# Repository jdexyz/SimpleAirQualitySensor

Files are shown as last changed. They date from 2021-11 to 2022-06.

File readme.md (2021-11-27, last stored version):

# (A) Simple Air Quality Sensor

### Parts

All parts were bought from https://shop.pimoroni.com/

- [Adafruit MagTag - 2.9" Grayscale E-Ink WiFi Display](https://www.adafruit.com/product/4800)
- [Adafruit CCS811 Air Quality Sensor Breakout](https://www.adafruit.com/product/3566)
- [Adafruit PMSA003I Air Quality Breakout](https://www.adafruit.com/product/4632)
- [Adafruit SCD-41 - True CO2 Temperature and Humidity Sensor](https://www.adafruit.com/product/5190)
- [MICS6814 3-in-1 Gas Sensor Breakout (CO, NO2, NH3)](https://shop.pimoroni.com/products/mics6814-gas-sensor-breakout)
- [BME688 4-in-1 Air Quality Breakout](https://shop.pimoroni.com/products/bme688-breakout)
- [LiPo Battery Pack – 2000mAh](https://shop.pimoroni.com/products/lipo-battery-pack?variant=20429082247)

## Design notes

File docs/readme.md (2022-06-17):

# (A) Simple Air Quality Sensor

### Parts

All parts were bought from https://shop.pimoroni.com/

- [Adafruit MagTag - 2.9" Grayscale E-Ink WiFi Display](https://www.adafruit.com/product/4800)
- [Adafruit CCS811 Air Quality Sensor Breakout](https://www.adafruit.com/product/3566)
- [Adafruit PMSA003I Air Quality Breakout](https://www.adafruit.com/product/4632)
- [Adafruit SCD-41 - True CO2 Temperature and Humidity Sensor](https://www.adafruit.com/product/5190)
- [MICS6814 3-in-1 Gas Sensor Breakout (CO, NO2, NH3)](https://shop.pimoroni.com/products/mics6814-gas-sensor-breakout)
- [BME688 4-in-1 Air Quality Breakout](https://shop.pimoroni.com/products/bme688-breakout)
- [LiPo Battery Pack – 2000mAh](https://shop.pimoroni.com/products/lipo-battery-pack?variant=20429082247)

## A clueless but quick method for creating 3D boards from Eagle

At some point, with the integration of Eagle in Fusion 360, I thought I could open Eagle board files from Adafruit/Sparkfun and get in one click a 3D model in Fusion 360.

This did not happen. I spent a few hours trying to get the libraries right, but I am still confused and definitely not successful. However, I can quickly get the board with rough components placed, which is enough for me.

I ended up doing the following :

1. Open the board in Eagle. I used the latest version of Eagle as of March 2022, Eagle 9.6.

2. Click on the Manufacturing tab on the right. Click on the settings icon, and choose "SolderMask Color". Choose the appropriate color.

3. Click on the Fusion 360 tab to create a new board there.

4. In Fusion, open the generated model. 

5. Find the board packages, then right click and "Save a Copy".

6. Open the new Packages model, it is now a normal 3D model, instead of a 3D PCB.

7. In the data panel, click on the previous 3D PCB model and insert it in the current model.

8. Break the link of the inserted model and delete its packages.

9. Next clean up the model, removing the rectangle placeholders in front of holes, vias, etc.

10. Then import all 3D models of important parts manually. I only did this for big components that matter in mechanical assembly.

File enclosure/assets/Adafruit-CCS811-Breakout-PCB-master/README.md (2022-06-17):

## Adafruit CCS811 Breakout PCB

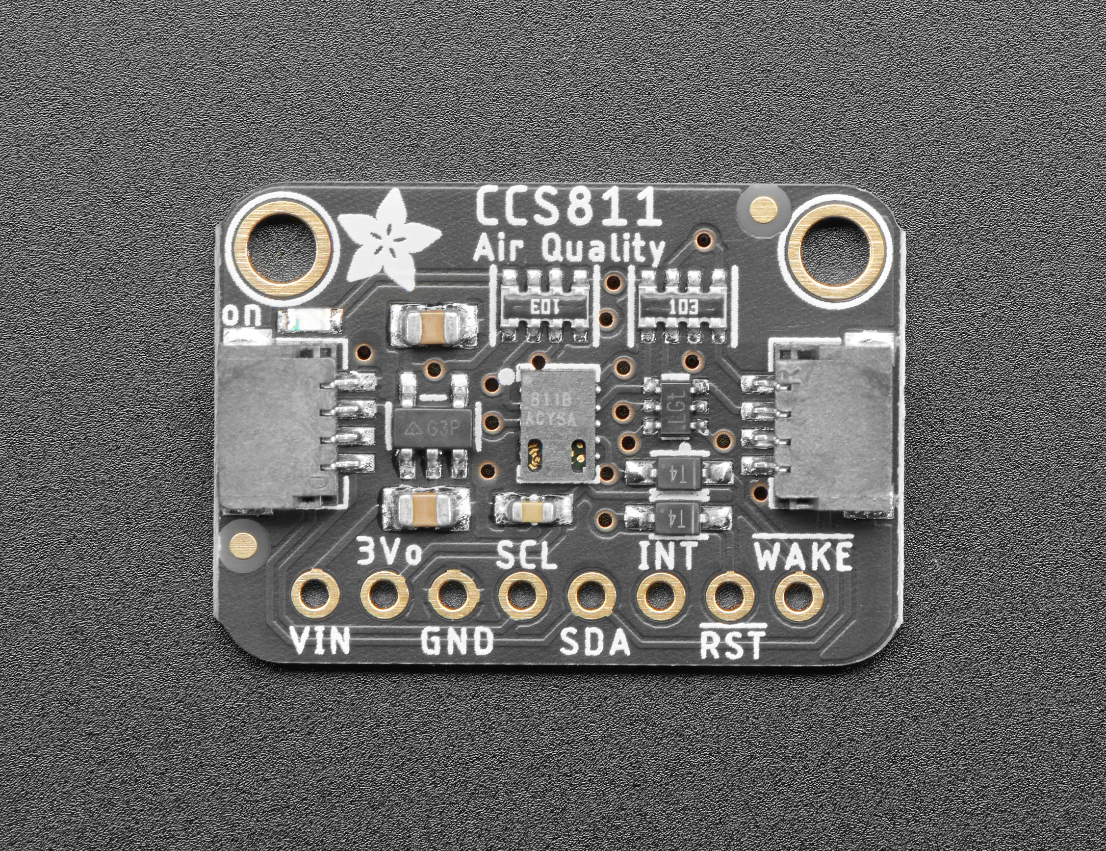
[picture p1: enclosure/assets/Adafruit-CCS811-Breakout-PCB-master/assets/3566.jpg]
<a href="http://www.adafruit.com/products/3566"><br/>
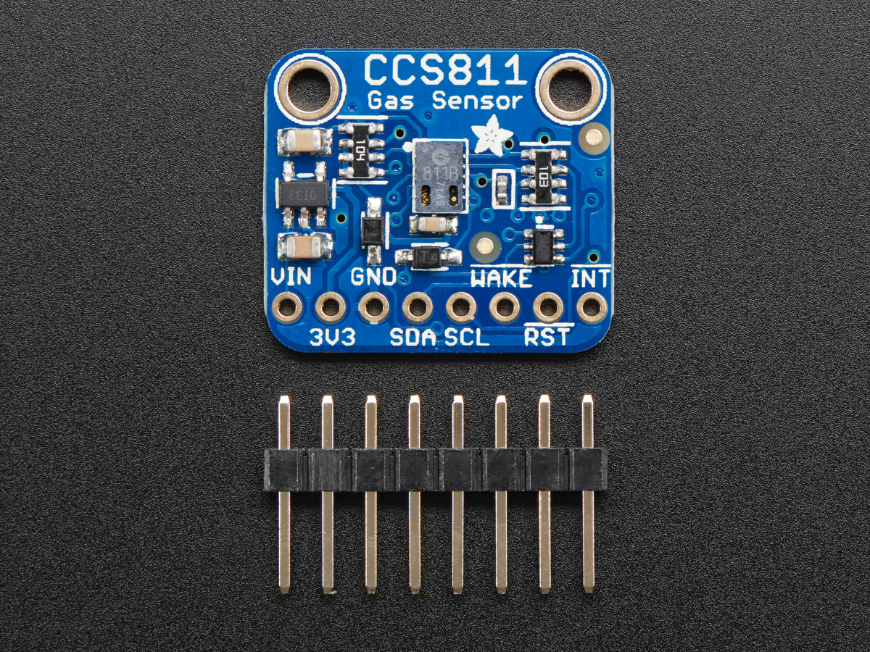
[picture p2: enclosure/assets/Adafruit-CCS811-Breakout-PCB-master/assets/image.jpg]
<a href="http://www.adafruit.com/products/3566"><br/>
Click here to purchase one from the Adafruit shop</a>

PCB files for the Adafruit CCS811 air quality sensor breakout board. Format is EagleCAD schematic and board layout

For more details, check out the product page at
* https://www.adafruit.com/products/3566

### Description

Breathe easy - we finally have an I2C VOC/eCO2 sensor in the Adafruit shop! Add air quality monitoring to your project and with an Adafruit CCS811 Air Quality Sensor Breakout. This sensor from AMS is a gas sensor that can detect a wide range of Volatile Organic Compounds (VOCs) and is intended for indoor air quality monitoring. When connected to your microcontroller (running our library code) it will return a Total Volatile Organic Compound (TVOC) reading and an equivalent carbon dioxide reading (eCO2) over I2C. There is also an onboard thermistor that can be used to calculate the local ambient temperature.

The CCS811 has a 'standard' hot-plate MOX sensor, as well as a small microcontroller that controls power to the plate, reads the analog voltage, and provides an I2C interface to read from.

This part will measure eCO2 (equivalent calculated carbon-dioxide) concentration within a range of 400 to 8192 parts per million (ppm), and TVOC (Total Volatile Organic Compound) concentration within a range of 0 to 1187 parts per billion (ppb). According to the fact sheet it can detect Alcohols, Aldehydes, Ketones, Organic Acids, Amines, Aliphatic and Aromatic Hydrocarbons. We include a 10K NTC thermistor with matching balancing resistor which can be read by the CCS811 to calculate approximate temperature.

Please note, this sensor, like all VOC/gas sensors, has variability and to get precise measurements you will want to calibrate it against known sources! That said, for general environmental sensors, it will give you a good idea of trends and comparisons.Also, AMS recommends that you run this sensor for 48 hours when you first receive it to "burn it in", and then 20 minutes in the desired mode every time the sensor is in use. This is because the sensitivity levels of the sensor will change during early use. Finally, this chip uses I2C clock stretching, and some microcontrollers/computers don't support that. It is now possible to [use with Raspberry Pi](https://learn.adafruit.com/circuitpython-on-raspberrypi-linux/i2c-clock-stretching).

The CCS811 has a configurable interrupt pin that can fire when a conversion is ready and/or when a reading crosses a user-settable threshold. The CCS811 supports multiple drive modes to take a measurement every 1 second, every 10 seconds, every 60 seconds, or every 250 milliseconds.

Nice sensor right? So we made it easy for you to get right into your next project. The surface-mount sensor is soldered onto a custom made PCB in the STEMMA QT form factor, making them easy to interface with. The STEMMA QT connectors on either side are compatible with the SparkFun Qwiic I2C connectors. This allows you to make solderless connections between your development board and the SGP30 or to chain it with a wide range of other sensors and accessories using a compatible cable.

For your convenience we've pick-and-placed the sensor on a PCB with a 3.3V regulator and some level shifting so it can be easily used with your favorite 3.3V or 5V microcontroller.
### License

Adafruit invests time and resources providing this open source design, please support Adafruit and open-source hardware by purchasing products from [Adafruit](https://www.adafruit.com)!

Designed by Limor Fried/Ladyada for Adafruit Industries.

Creative Commons Attribution/Share-Alike, all text above must be included in any redistribution. See license.txt for additional details.

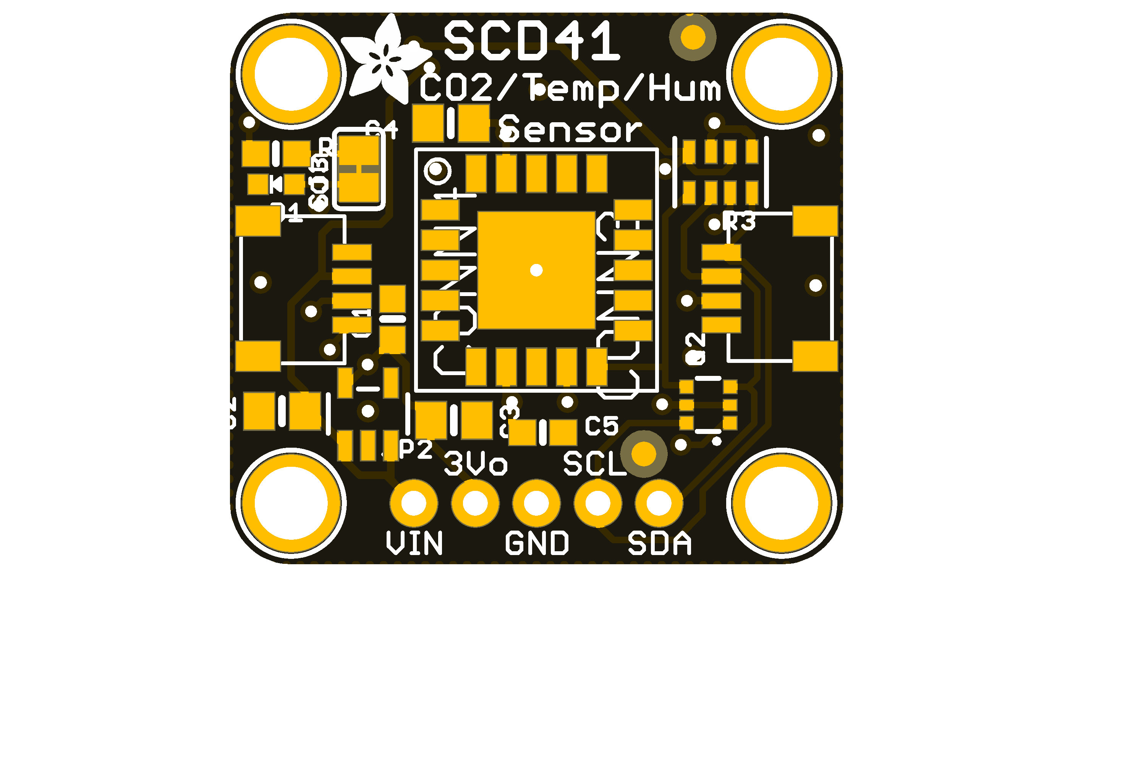
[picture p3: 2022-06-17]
enclosure/assets/Adafruit-SCD-4x-PCB-main/Adafruit SCD-41_top.png

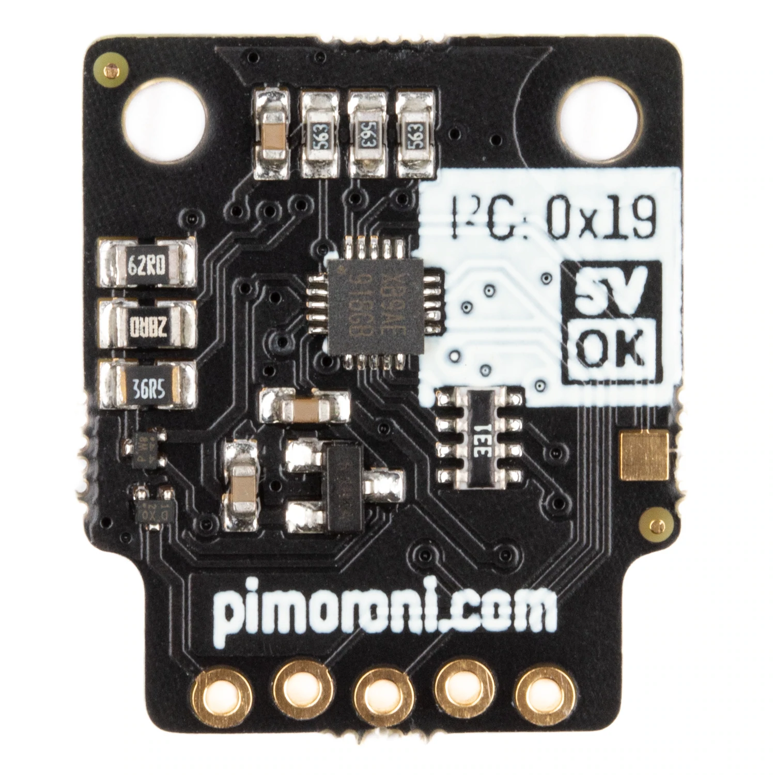
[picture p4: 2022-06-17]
enclosure/assets/MICS6814/MICS6814breakout_3of3_1500x1500.png

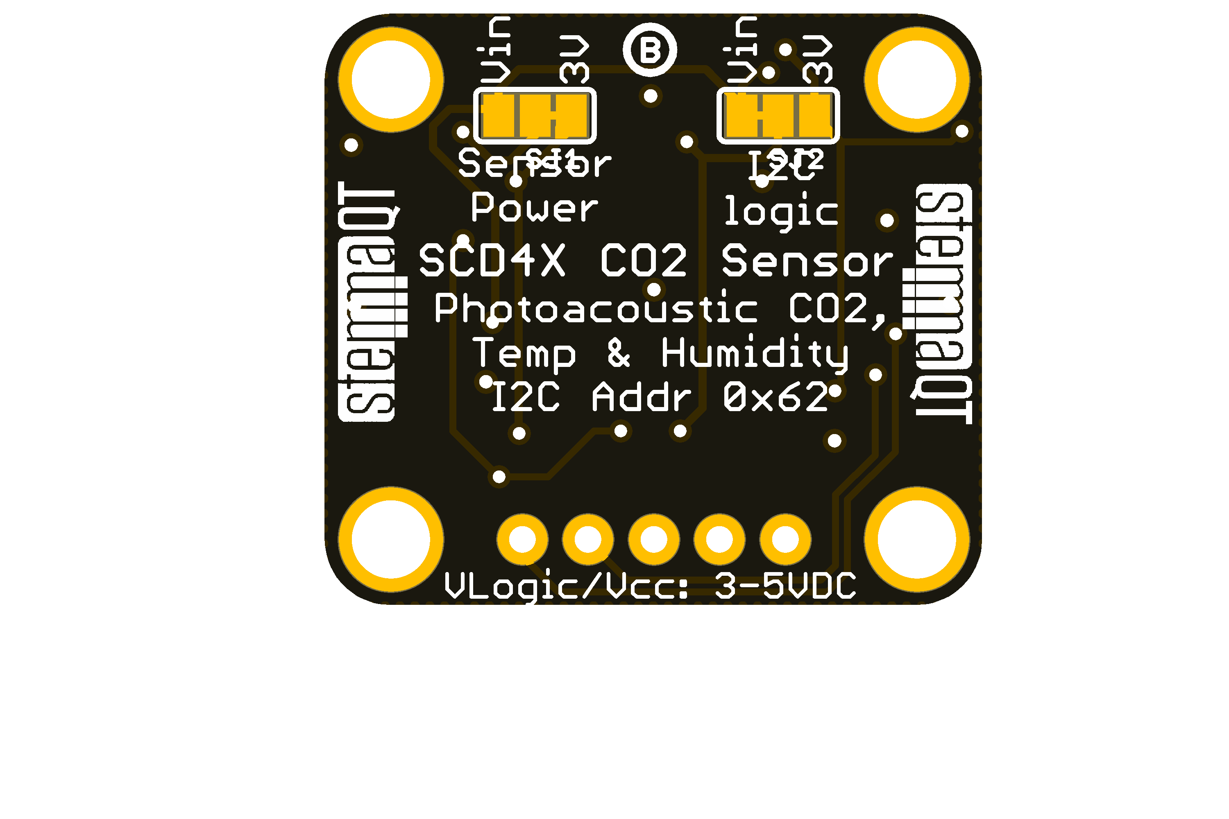
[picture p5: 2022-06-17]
enclosure/assets/Adafruit-SCD-4x-PCB-main/Adafruit SCD-41_bottom.png

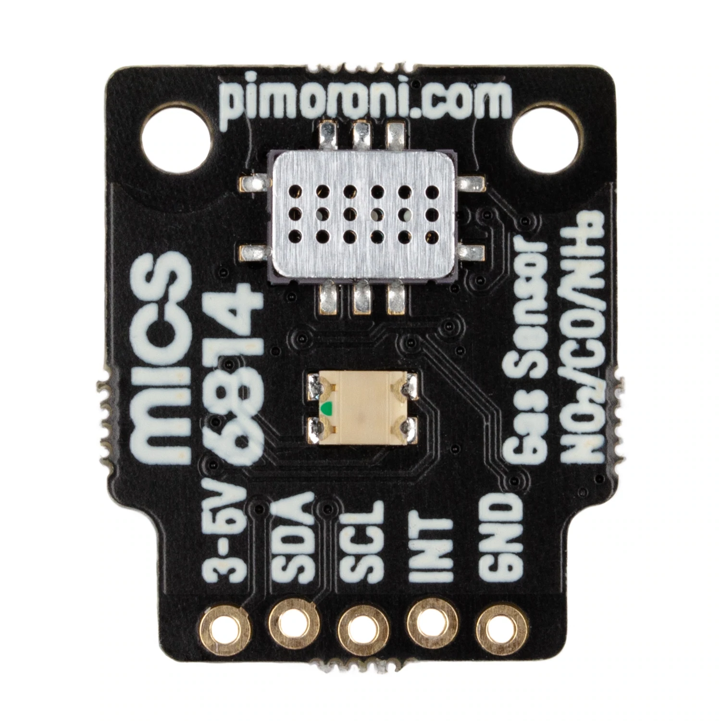
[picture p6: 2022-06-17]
enclosure/assets/MICS6814/MICS6814breakout_2of3_1500x1500.png

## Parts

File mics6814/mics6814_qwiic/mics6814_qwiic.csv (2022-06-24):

Id | Designator | Package | Quantity | Designation | Supplier and ref |  | H
1 | R8,R7 | 805 | 2 | 10k |  | k
2 | JP8 | SMT-JUMPER_2_NC_TRACE_SILK | 1 | PULL UP SCL
3 | JP7 | SMT-JUMPER_2_NC_TRACE_SILK | 1 | PULL UP SDA
4 | JP4 | SMT-JUMPER_2_NC_TRACE_SILK | 1 | HEAT LED
5 | JP2 | SMT-JUMPER_2_NC_TRACE_SILK | 1 | Power LED
6 | JP5 | SMT-JUMPER_2_NC_TRACE_SILK | 1 | alert
7 | U2 | SOT353 | 1 | 74HC1G04 |  | k
8 | Q1 | SOT23-3 | 1 | MOSFET_PCH-DMG2307L |  | K
9 | 1uH | 805 | 1 | INDUCTOR-0805-3.3UH |  | K
10 | 1uF | 805 | 1 | 1.0UF-0805-25V-10% |  | K
11 | MICS6814 | MICS6814 | 1 | MiCS-6814 |  | K
12 | D2 | LED-0603 | 1 | LED-RED1206 |  | K
13 | R6,R1 | 805 | 2 | 56k |  | K
14 | R5 | 805 | 1 | 1K |  | K
15 | R4 | 805 | 1 | 75R |  | K
16 | R3 | 805 | 1 | 10R |  | K
17 | R2 | 805 | 1 | 510R |  | K
18 | D1 | LED-0603 | 1 | Power |  | K
19 | JP6 | SMT-JUMPER_3_1-NC_TRACE_SILK | 1 | VSW
20 | JP3 | SMT-JUMPER_3_NO_SILK | 1 | ADDR2
21 | JP1 | SMT-JUMPER_3_1-NC_TRACE_SILK | 1 | ADDR1
22 | J2,J1 | 1X04_1MM_RA | 2 | QWIIC_CONNECTORJS-1MM |  | K
23 | U1 | TSSOP-10_3x3mm_P0.5mm | 1 | ADS1115 |  | K

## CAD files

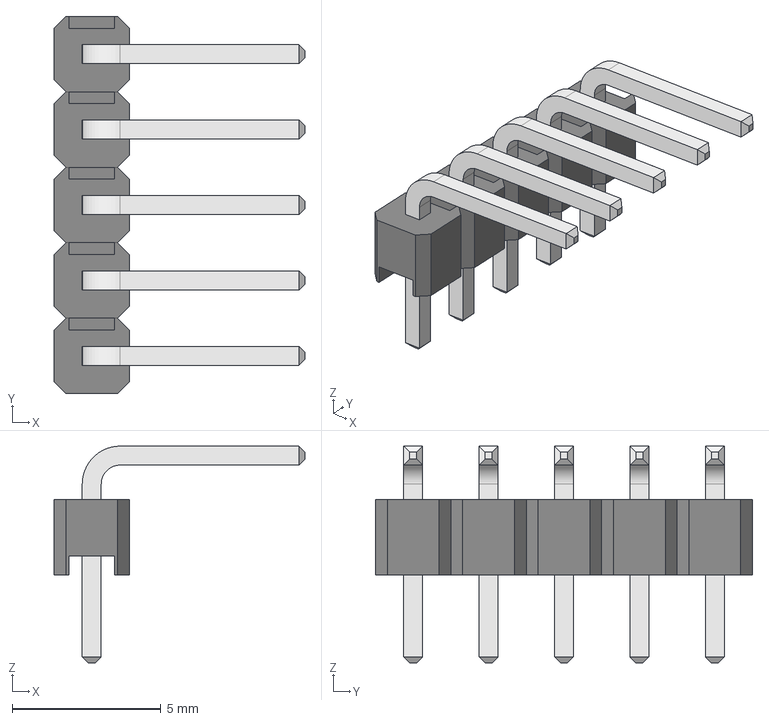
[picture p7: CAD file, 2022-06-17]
enclosure/assets/MICS6814/5Pin.step
8.45 x 12.7 x 7.30 mm

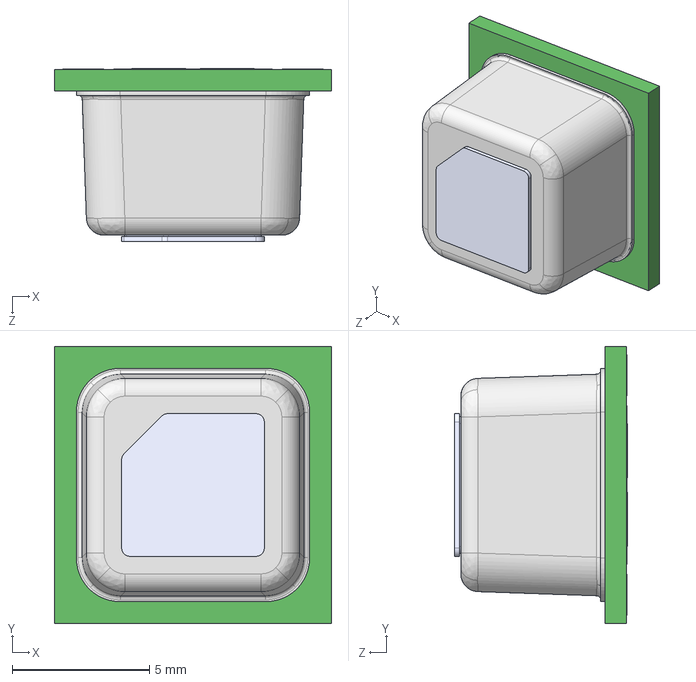
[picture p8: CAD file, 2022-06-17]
enclosure/assets/SCD41-D-R2--3DModel-STEP-369182.STEP
10.1 x 10.1 x 6.31 mm

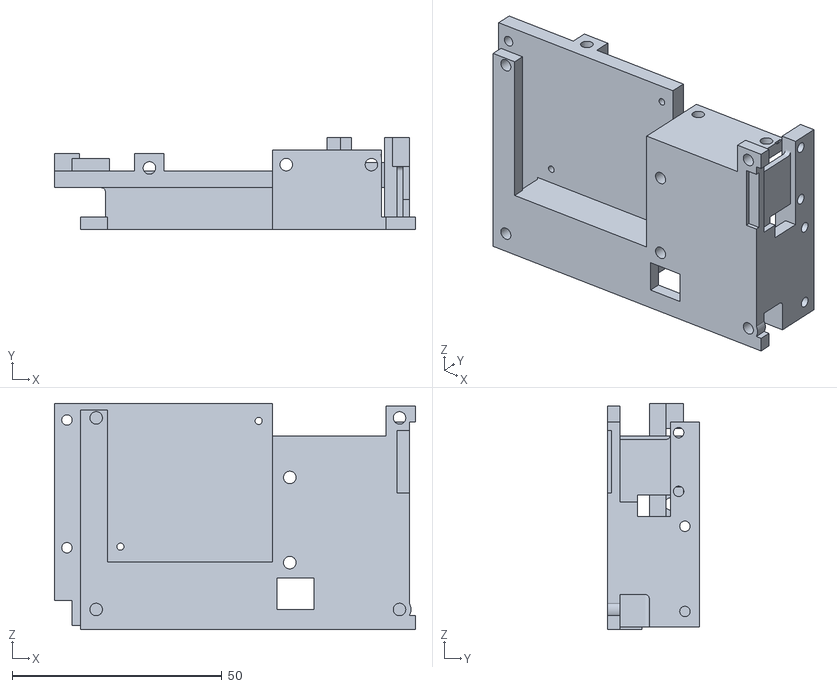
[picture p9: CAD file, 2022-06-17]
enclosure/exports/Inner.stl
86.1 x 22.0 x 54.0

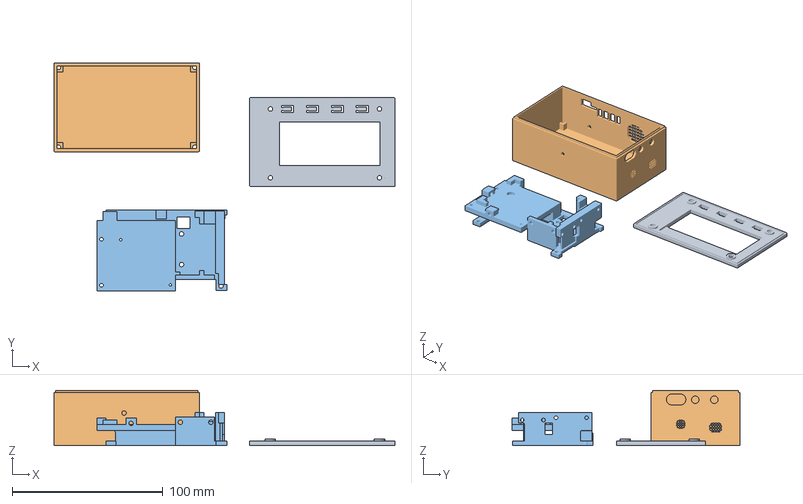
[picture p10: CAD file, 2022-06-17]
enclosure/Print.3mf
226.4 x 151.6 x 36.7 mm
Top.stl
Outer.stl
Inner.stl

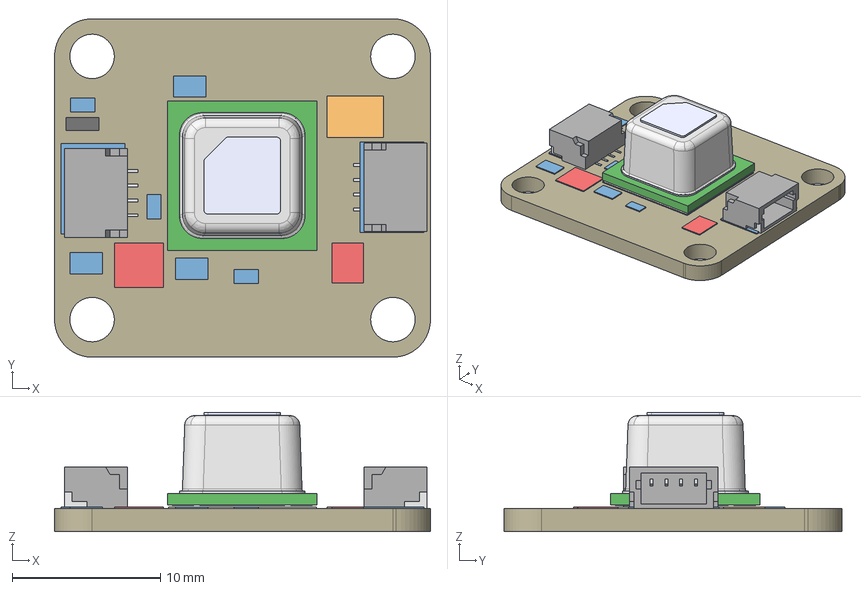
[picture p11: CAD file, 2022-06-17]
enclosure/src/Adafruit SCD-41 v13.step
25.4 x 22.9 x 8.07 mm
0805-NO x 3
SOT23-5
0603-NO x 3
RESPACK_4X0603
SOT363
JST_SH4 x 2
STEMMAQT x 2
CHIPLED_0603_NOOUTLINE
SCD41
SOLDERJUMPER_2WAY_OPEN_NOPASTE x 2
SOLDERJUMPER_CLOSEDWIRE
Board v2
STEMMA_I2C_QT
STEMMA_I2C_QT_1
SCD41-D-R2--3DModel-STEP-369182 v1

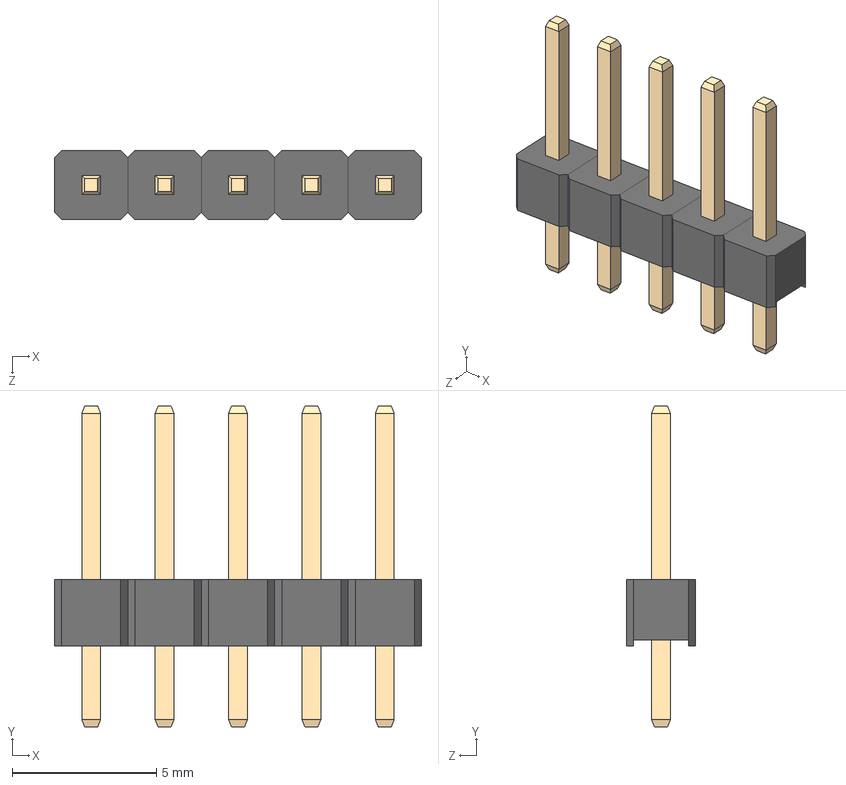
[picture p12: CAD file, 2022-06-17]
enclosure/assets/MICS6814/5x_Male_Pin_2.54_mm.STEP
12.7 x 11.1 x 2.40 mm
1_Male_Pin_2.54_mm x 5

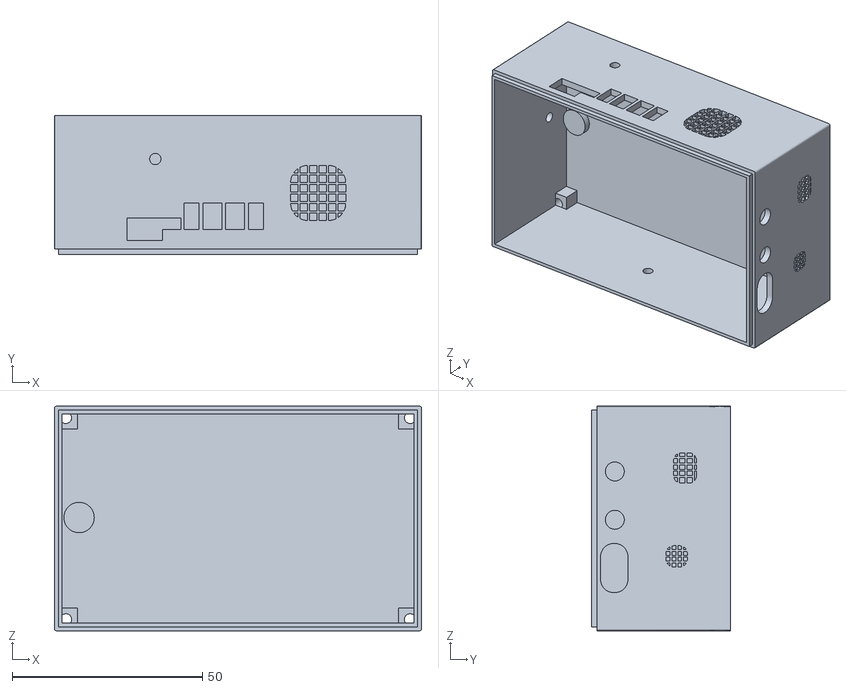
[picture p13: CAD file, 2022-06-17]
enclosure/exports/Outer.stl
96.5 x 36.7 x 59.1

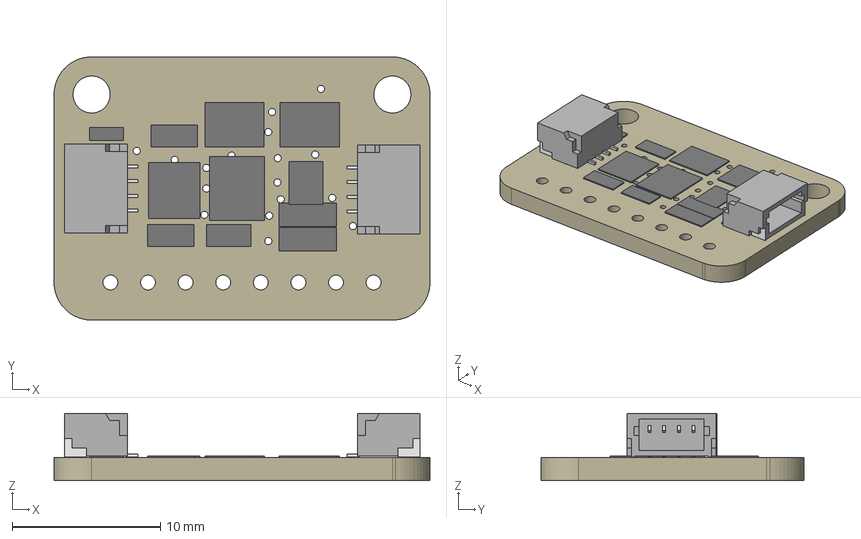
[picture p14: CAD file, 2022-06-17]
enclosure/src/Adafruit CCS811 STEMMA QT v3.step
25.4 x 17.8 x 4.56 mm
0603-NO
0805-NO x 2
1X08_ROUND_70
ADAFRUIT_3.5MM x 2
CCS811
CHIPLED_0603_NOOUTLINE
FIDUCIAL_1MM x 2
JST_SH4 x 2
MOUNTINGHOLE_2.5_PLATED x 2
PCBFEAT-REV-040
RESPACK_4X0603 x 2
SOD-323 x 2
SOLDERJUMPER_ARROW_NOPASTE
SOLDERJUMPER_CLOSEDWIRE
SOT23-5
SOT363
STEMMAQT x 2
Board
STEMMA_I2C_QT
STEMMA_I2C_QT_1

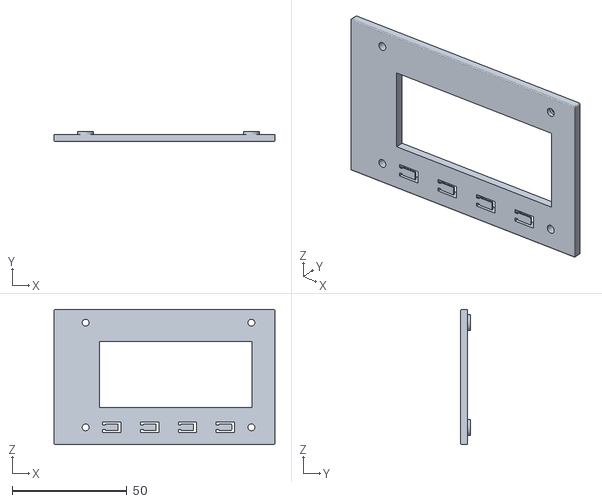
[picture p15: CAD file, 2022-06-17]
enclosure/exports/Top.stl
96.5 x 4.37 x 59.1

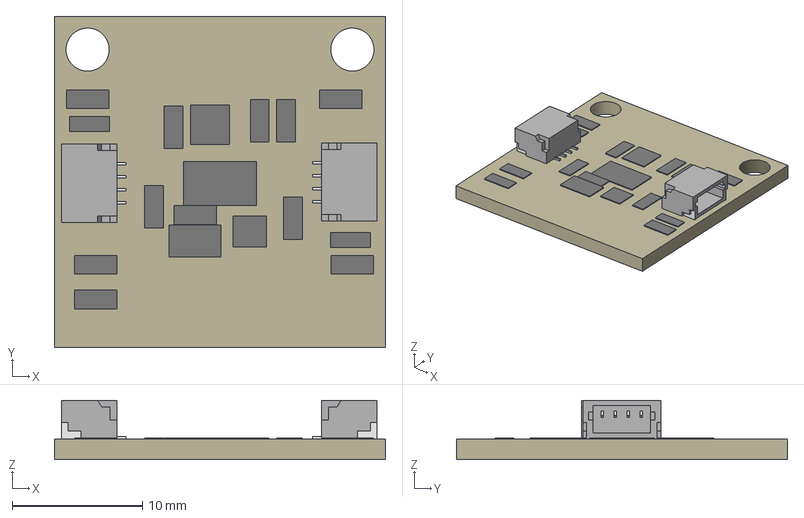
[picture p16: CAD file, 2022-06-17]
enclosure/src/Qwiic Power Switch v3.step
25.4 x 25.4 x 4.55 mm
GPIO10 x 2
GPIO20 x 2
IN0
IN0 (1)
LED_IN0
LED_OUT0
GND1 x 4
SCL9 x 4
SDA8 x 4
I_SUPER2_C-()-03 x 2
OUT0
OUT0 (1)
POWER0
QWIIC0
CREATIVE_COMMONS
FIDUCIAL-1X2 x 4
OSHW-LOGO-MINI
1X01_NO_SILK x 2
1X04_NO_SILK x 2
JST04_1MM_RA x 2
SOT23-3
STAND-OFF x 2
VSSOP_8PIN
MSOP8
SOT353
SMT-JUMPER_2_NC_TRACE_SILK x 2
SMT-JUMPER_3_2-NC_TRACE_SILK x 2
LED-0603 x 2
SPARKX-MEDIUM
SWITCH0
Qwiic Power Switch_Board v1
STEMMA_I2C_QT
STEMMA_I2C_QT_1

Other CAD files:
enclosure/assets/4632 PMSA003I.f3d
enclosure/assets/Adafruit-SCD-4x-PCB-main/Adafruit SCD-41 v6.f3d
enclosure/assets/Adafruit-SCD-4x-PCB-main/Board.f3d
enclosure/assets/Adafruit-SCD-4x-PCB-main/JST_SH4.f3d
enclosure/assets/MICS6814/mics-6814_three_gas_sensor.7066ebe4-298e-4c48-8aa3-1ca8056fe42b.f3d
enclosure/src/Adafruit CCS811 STEMMA QT v3.f3d
enclosure/src/Adafruit SCD-41 v13.f3d
enclosure/src/Qwiic Power Switch v3.f3d

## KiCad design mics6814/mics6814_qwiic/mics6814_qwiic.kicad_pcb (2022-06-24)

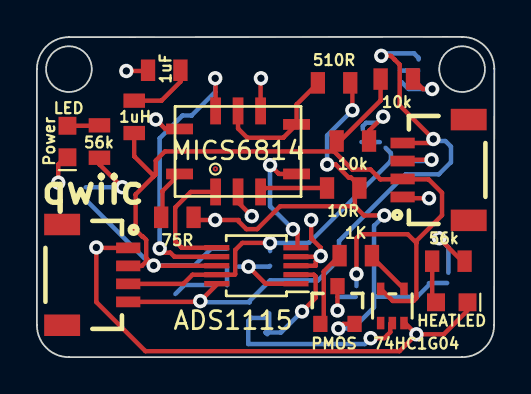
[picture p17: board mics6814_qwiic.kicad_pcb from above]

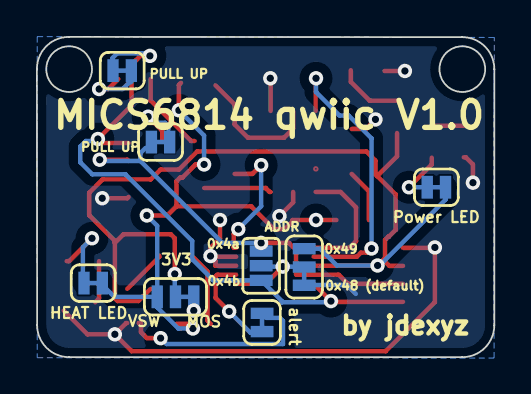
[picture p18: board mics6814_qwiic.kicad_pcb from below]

Board: 2 copper layers, 25.4 x 17.8 mm, 26 parts (8 on the bottom side), 24 nets.

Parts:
1uF: 1.0UF-0805-25V-10%; 0805
1uH: INDUCTOR-0805-3.3UH; 0805
ADS1115: ADS1115; MSOP-10_3x3mm_P0.5mm
D1: Power; LED-0603
D2: LED-RED1206; LED-0603
J1, J2: QWIIC_CONNECTORJS-1MM; 1X04_1MM_RA
JP1: ADDR1; SMT-JUMPER_3_1-NC_TRACE_SILK
JP2: Power LED; SMT-JUMPER_2_NC_TRACE_SILK
JP3: ADDR2; SMT-JUMPER_3_NO_SILK
JP4: HEAT LED; SMT-JUMPER_2_NC_TRACE_SILK
JP5: alert; SMT-JUMPER_2_NC_TRACE_SILK
JP6: VSW; SMT-JUMPER_3_1-NC_TRACE_SILK
JP7: PULL UP SDA; SMT-JUMPER_2_NC_TRACE_SILK
JP8: PULL UP SCL; SMT-JUMPER_2_NC_TRACE_SILK
MICS6814: MiCS-6814; MICS6814
Q1: MOSFET_PCH-DMG2307L; SOT23-3
R1, R6: 56k; 0805
R2: 510R; 0805
R3: 10R; 0805
R4: 75R; 0805
R5: 1K; 0805
R7, R8: 10k; 0805
U2: 74HC1G04; SOT353

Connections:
+3V3: 1uH.1, ADS1115.8 (VDD), J1.2 (VCC), J2.2 (VCC), JP1.1, JP2.2, JP6.2, R7.1, R8.1, U2.5 (P$V+)
+VSW: JP4.2, JP6.1, Q1.2 (S), R2.1, R3.2, R4.2
/ADDR: ADS1115.1 (ADDR), JP1.2, JP3.2
/ALERT: ADS1115.2 (ALERT/RDY), JP5.2
/CO_R: ADS1115.7 (AIN3), MICS6814.H
/NH3_R: ADS1115.5 (AIN1), MICS6814.D
/NO2_R: ADS1115.6 (AIN2), MICS6814.A
/SCL: ADS1115.10 (SCL), J1.4 (SCL), J2.4 (SCL), JP3.1, JP7.2
/SDA: ADS1115.9 (SDA), J1.3 (SDA), J2.3 (SDA), JP3.3, JP8.2
GND: 1uF.2, ADS1115.3 (GND), ADS1115.4 (AIN0), D1.C, D2.C, J1.1 (GND), J2.1 (GND), JP1.3, MICS6814.B, MICS6814.F, MICS6814.J, U2.3 (P$V-)
unnamed: D1.A, R1.1
unnamed: MICS6814.C, R3.1
unnamed: MICS6814.E, MICS6814.G, R2.2
unnamed: MICS6814.K, R4.1
unnamed: JP2.1, R1.2
unnamed: JP7.1, R7.2
unnamed: JP8.1, R8.2
unnamed: 1uF.1, 1uH.2
unnamed: Q1.1 (G), R5.2
unnamed: JP6.3, Q1.3 (D)
unnamed: R5.1, U2.4 (Y)
unnamed: D2.A, R6.1
unnamed: JP4.1, R6.2
unnamed: JP5.1, U2.2 (A)

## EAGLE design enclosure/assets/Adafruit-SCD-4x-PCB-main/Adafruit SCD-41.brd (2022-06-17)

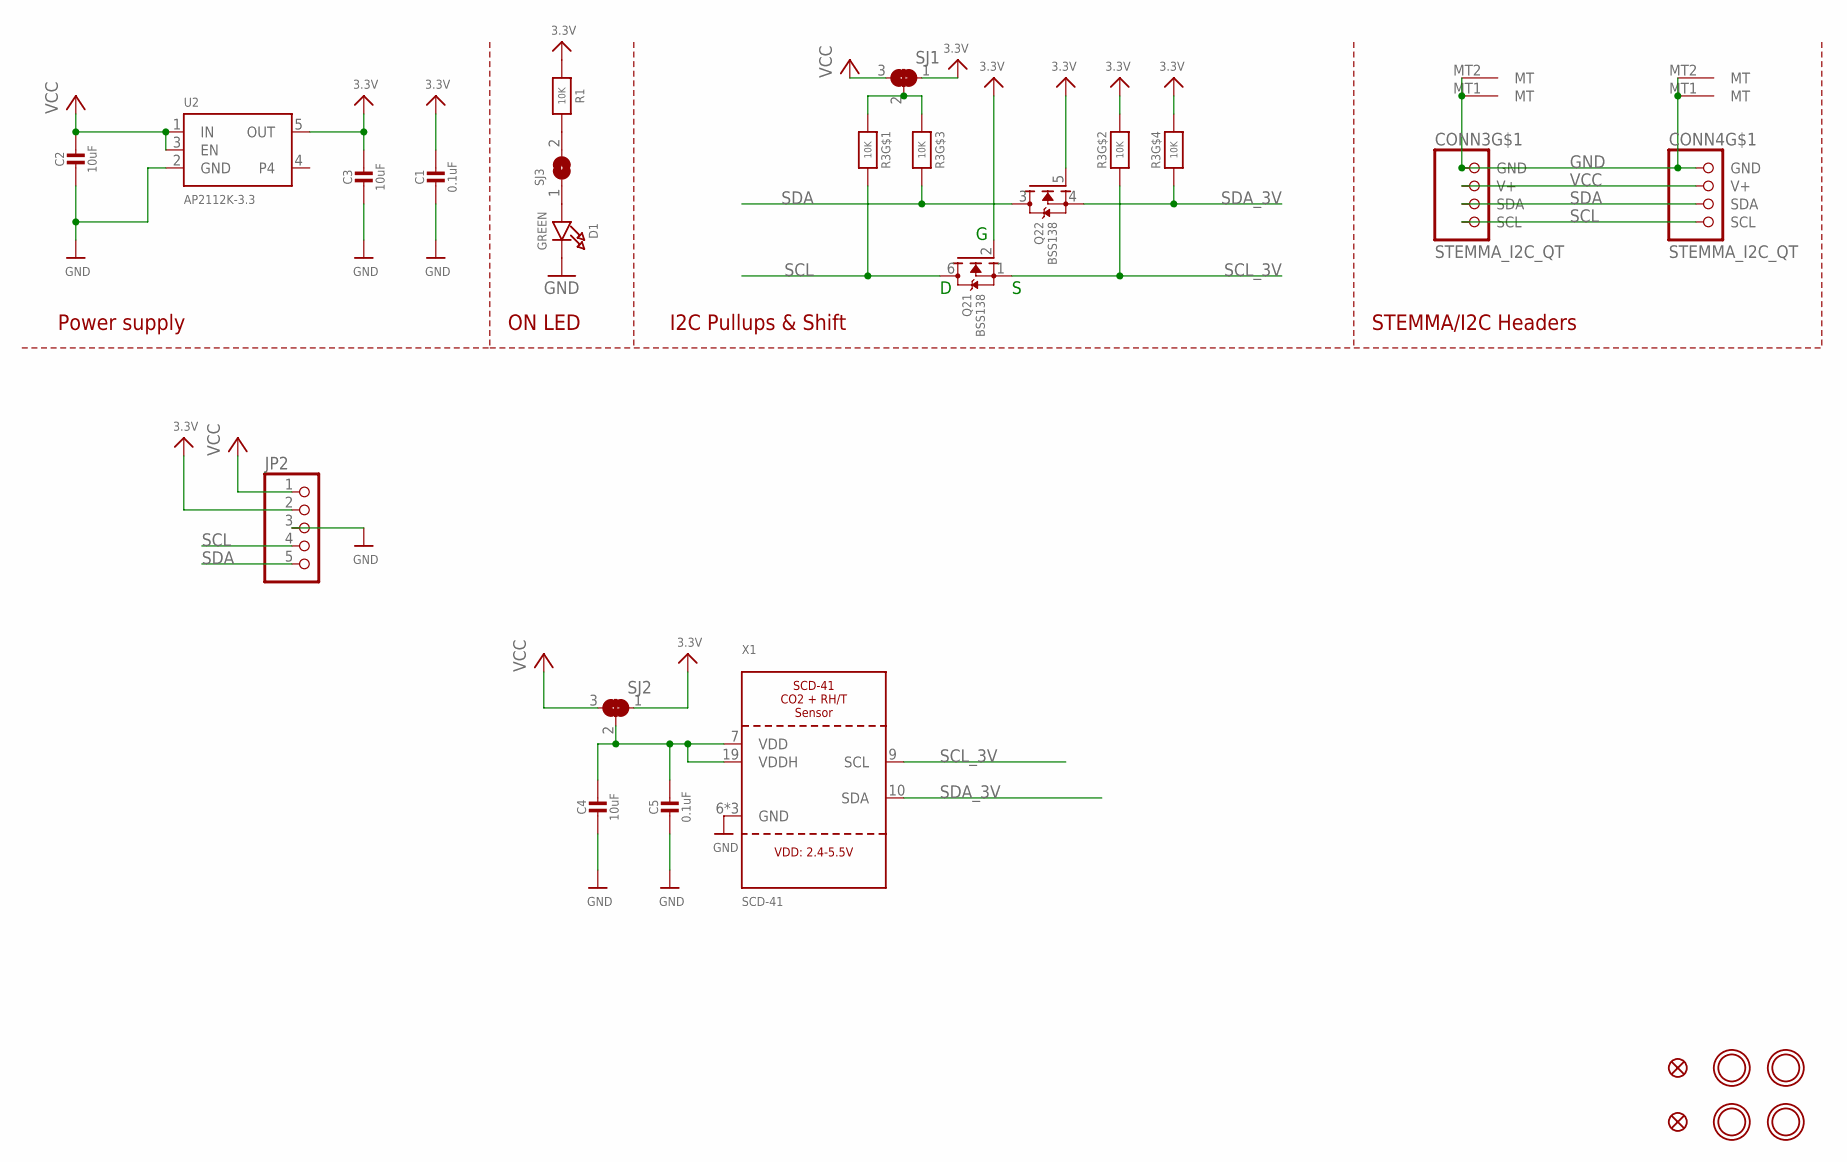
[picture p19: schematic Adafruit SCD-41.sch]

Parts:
C1, C5: 0.1uF; 0603-NO
C2, C3, C4: 10uF; 0805-NO
CONN3, CONN4: STEMMA_I2C_QT; JST_SH4
D1: GREEN; CHIPLED_0603_NOOUTLINE
FID3, FID4: FIDUCIAL_1MM
JP2: HEADER-1X576MIL; 1X05_ROUND_76
Q2: BSS138; SOT363
R1: 10K; 0603-NO
R3: 10K; RESPACK_4X0603
SJ1, SJ2: SOLDERJUMPER_2WAY; SOLDERJUMPER_2WAY_OPEN_NOPASTE
SJ3: SOLDERJUMPERCLOSED; SOLDERJUMPER_CLOSEDWIRE
U2: AP2112K-3.3; SOT23-5
U$1, U$17, U$19, U$21: MOUNTINGHOLE3.0THIN; MOUNTINGHOLE_3.0_PLATEDTHIN
X1: SCD-41; SCD41

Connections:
3.3V: C1.1, C3.1, JP2.2, Q2.2 (G), Q2.5 (G), R1.1, R3.2 (1), R3.4 (1), SJ1.1, SJ2.1, U2.5 (OUT)
GND: C1.2, C2.2, C3.2, C4.2, C5.2, CONN3.1 (GND), CONN3.MT1 (MT), CONN3.MT2 (MT), CONN4.1 (GND), CONN4.MT1 (MT), CONN4.MT2 (MT), D1.C, JP2.3, U2.2 (GND), X1.6 (GND), X1.20 (GND), X1.P$1 (GND)
unnamed: D1.A, SJ3.1
unnamed: R3.1, R3.3 (1), SJ1.2
unnamed: C4.1, C5.1, SJ2.2, X1.7 (VDD), X1.19 (VDDH)
unnamed: R1.2, SJ3.2
SCL: CONN3.4 (SCL), CONN4.4 (SCL), JP2.4, Q2.6 (D), R3.8 (2)
SCL_3V: Q2.1 (S), R3.7 (2), X1.9 (SCL)
SDA: CONN3.3 (SDA), CONN4.3 (SDA), JP2.5, Q2.3 (D), R3.6 (2)
SDA_3V: Q2.4 (S), R3.5 (2), X1.10 (SDA)
VCC: C2.1, CONN3.2 (V+), CONN4.2 (V+), JP2.1, SJ1.3, SJ2.3, U2.1 (IN), U2.3 (EN)

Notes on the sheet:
I2C Pullups & Shift
STEMMA/I2C Headers
ON LED
Power supply

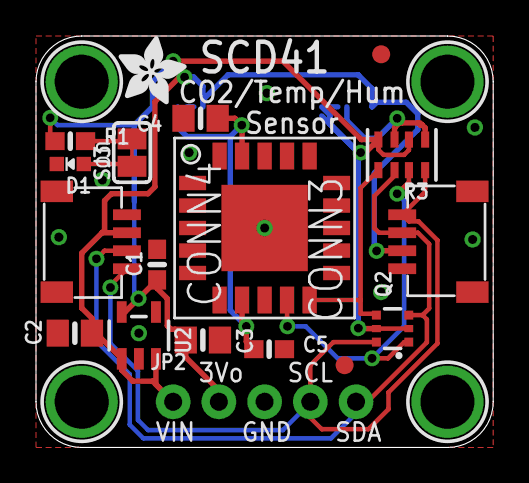
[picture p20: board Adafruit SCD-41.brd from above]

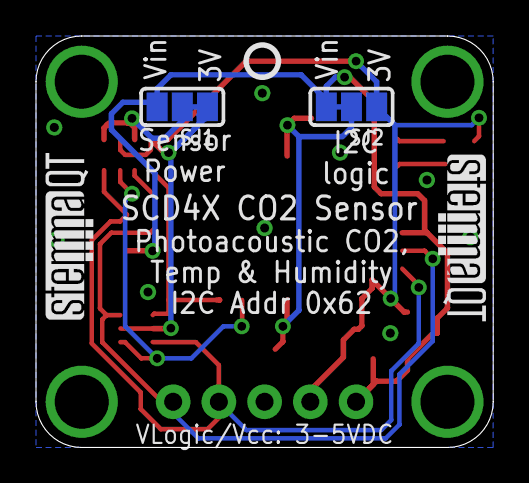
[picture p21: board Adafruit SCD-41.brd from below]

Board: 2 copper layers, 25.4 x 22.9 mm, 27 parts (5 on the bottom side), 11 nets.

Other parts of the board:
U$22: ADAFRUIT_3.5MM
U$25: PCBFEAT-REV-040
U$30, U$31: STEMMAQT

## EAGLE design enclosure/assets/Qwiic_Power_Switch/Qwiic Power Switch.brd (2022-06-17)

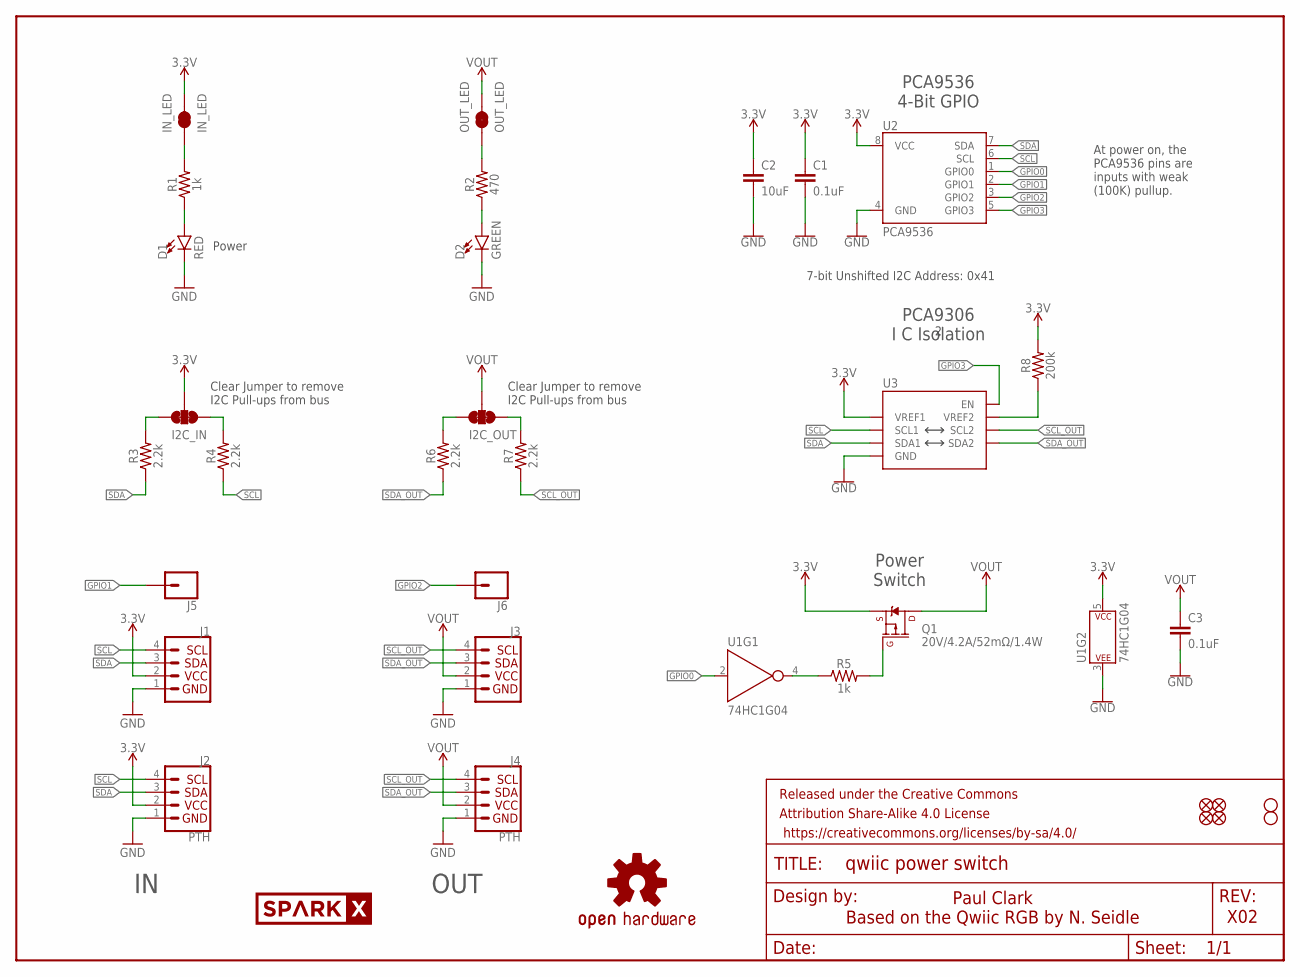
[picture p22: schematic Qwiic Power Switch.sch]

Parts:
C1, C3: 0.1uF; 0603
C2: 10uF; 0603
D1: RED; LED-0603
D2: GREEN; LED-0603
FRAME1: FRAME-LETTER; CREATIVE_COMMONS
I2C_IN, I2C_OUT: JUMPER-SMT_3_2-NC_TRACE_SILK; SMT-JUMPER_3_2-NC_TRACE_SILK
IN_LED: IN_LED; SMT-JUMPER_2_NC_TRACE_SILK
J1, J3: Qwiic Right Angle; JST04_1MM_RA
J2, J4: PTH; 1X04_NO_SILK
J5, J6: CONN_01PTH_NO_SILK_YES_STOP; 1X01_NO_SILK
JP1, JP2, JP5, JP6: FIDUCIAL1X2; FIDUCIAL-1X2
JP3, JP4: STAND-OFF
LOGO1: OSHW-LOGOMINI; OSHW-LOGO-MINI
OUT_LED: OUT_LED; SMT-JUMPER_2_NC_TRACE_SILK
Q1: 20V/4.2A/52mΩ/1.4W; SOT23-3
R1, R5: 1k; 0603
R2: 470; 0603
R3, R4, R6, R7: 2.2k; 0603
R8: 200k; 0603
U1: 74HC1G04; SOT353
U2: PCA9536; MSOP8
U3: PCA9306VSSOP_8PIN; VSSOP_8PIN
U$2: SPARKX-LOGO4; SPARKX-MEDIUM

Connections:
3.3V: C1.1, C2.1, I2C_IN.2, IN_LED.2, J1.2, J2.2, Q1.2 (S), R8.2, U1.5 (P$V+), U2.8 (VCC), U3.P2 (VREF1)
GND: C1.2, C2.2, C3.2, D1.C, D2.C, J1.1, J2.1, J3.1, J4.1, U1.3 (P$V-), U2.4 (GND), U3.P1 (GND)
GPIO0: U1.2 (A), U2.1 (GPIO0)
GPIO1: J5.1, U2.2 (GPIO1)
GPIO2: J6.1, U2.3 (GPIO2)
GPIO3: U2.5 (GPIO3), U3.P8 (EN)
unnamed: I2C_IN.1, R4.2
unnamed: I2C_IN.3, R3.2
unnamed: D1.A, R1.1
unnamed: IN_LED.1, R1.2
unnamed: R5.1, U1.4 (Y)
unnamed: Q1.1 (G), R5.2
unnamed: OUT_LED.1, R2.2
unnamed: I2C_OUT.1, R7.2
unnamed: D2.A, R2.1
unnamed: I2C_OUT.3, R6.2
unnamed: R8.1, U3.P7 (VREF2)
SCL: J1.4, J2.4, R4.1, U2.6 (SCL), U3.P3 (SCL1)
SCL_OUT: J3.4, J4.4, R7.1, U3.P6 (SCL2)
SDA: J1.3, J2.3, R3.1, U2.7 (SDA), U3.P4 (SDA1)
SDA_OUT: J3.3, J4.3, R6.1, U3.P5 (SDA2)
VOUT: C3.1, I2C_OUT.2, J3.2, J4.2, OUT_LED.2, Q1.3 (D)

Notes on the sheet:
Paul Clark Based on the Qwiic RGB by N. Seidle
X02
Clear Jumper to remove I2C Pull-ups from bus
Power
7-bit Unshifted I2C Address: 0x41
OUT
At power on, the PCA9536 pins are inputs with weak (100K) pullup.
PCA9536 4-Bit GPIO
PCA9306 I C Isolation
Power Switch

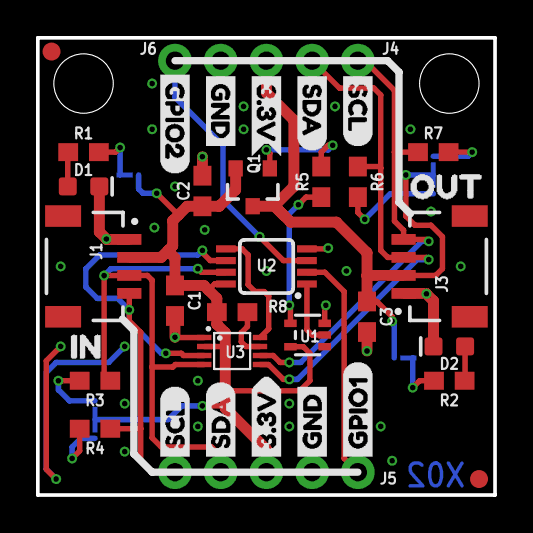
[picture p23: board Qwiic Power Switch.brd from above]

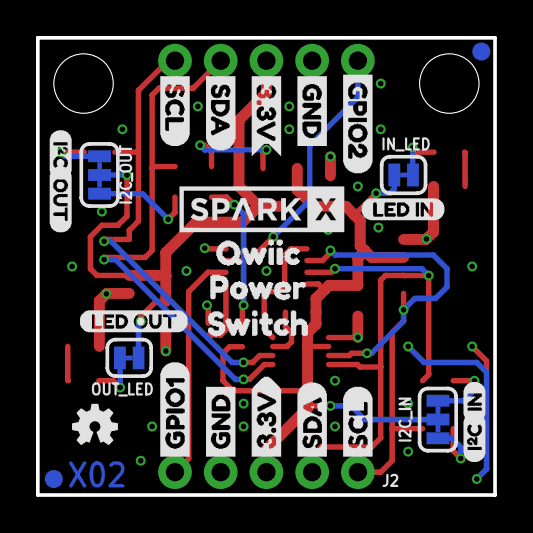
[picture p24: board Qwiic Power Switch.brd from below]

Board: 2 copper layers, 25.4 x 25.4 mm, 67 parts (28 on the bottom side), 22 nets.

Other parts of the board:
U$1, U$28: IN0
U$3, U$8, U$13, U$22: GND1
U$4, U$7, U$12, U$23: 3#3V0
U$5, U$11, U$15, U$27: SDA8
U$6, U$9, U$17, U$26: SCL9
U$10, U$18: I_SUPER2_C-()-03
U$14, U$31: OUT0
U$16, U$24: GPIO10
U$19: QWIIC0
U$20, U$25: GPIO20
U$29: LED_IN0
U$30: LED_OUT0
U$32: POWER0
U$34: SWITCH0

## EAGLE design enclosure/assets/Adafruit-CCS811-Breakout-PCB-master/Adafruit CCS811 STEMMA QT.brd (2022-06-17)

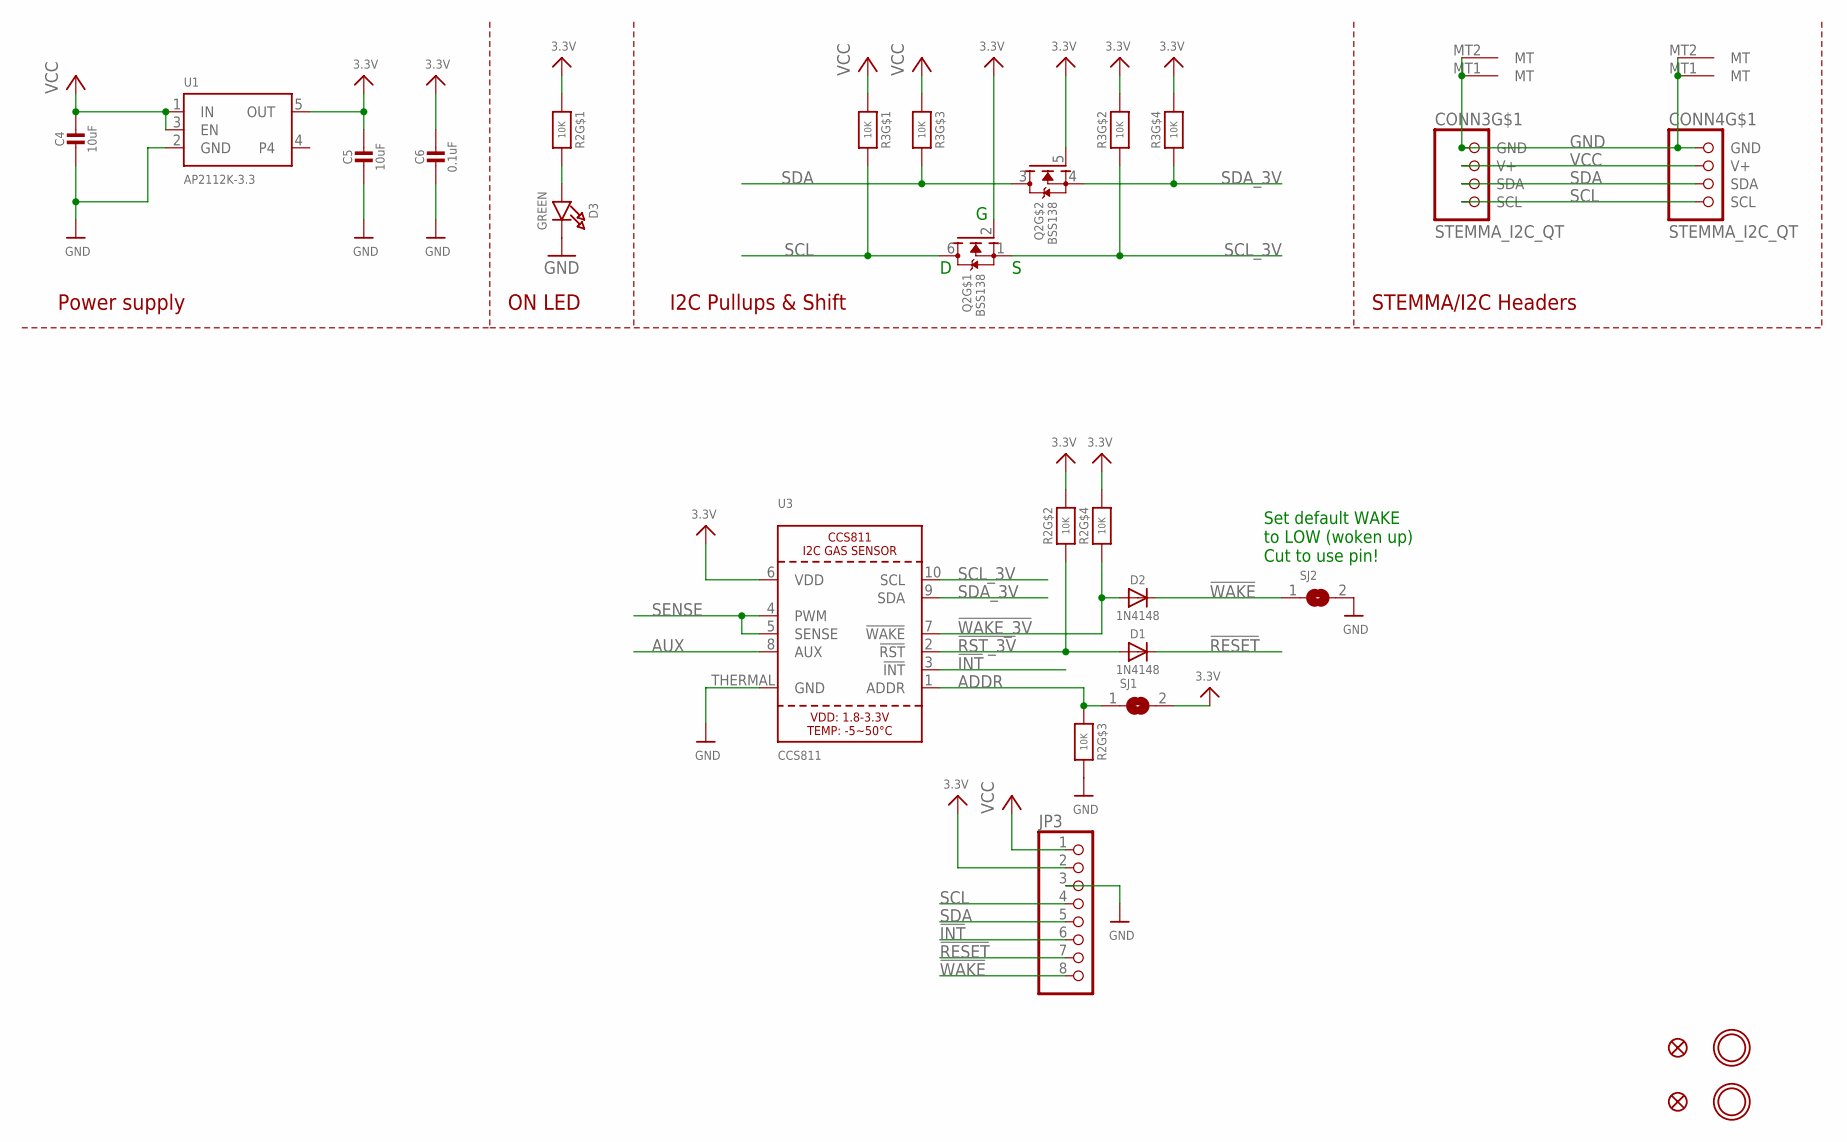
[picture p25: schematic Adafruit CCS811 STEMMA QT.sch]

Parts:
C4, C5: 10uF; 0805-NO
C6: 0.1uF; 0603-NO
CONN3, CONN4: STEMMA_I2C_QT; JST_SH4
D1, D2: 1N4148; SOD-323
D3: GREEN; CHIPLED_0603_NOOUTLINE
FID3, FID4: FIDUCIAL_1MM
JP3: HEADER-1X870MIL; 1X08_ROUND_70
Q2: BSS138; SOT363
R2, R3: 10K; RESPACK_4X0603
SJ1: SOLDERJUMPER; SOLDERJUMPER_ARROW_NOPASTE
SJ2: SOLDERJUMPERCLOSED; SOLDERJUMPER_CLOSEDWIRE
U1: AP2112K-3.3; SOT23-5
U3: CCS811
U$39, U$40: MOUNTINGHOLE2.5; MOUNTINGHOLE_2.5_PLATED

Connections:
3.3V: C5.1, C6.1, JP3.2, Q2.2 (G), Q2.5 (G), R2.1, R2.5 (2), R2.7 (2), R3.2 (1), R3.4 (1), SJ1.2, U1.5 (OUT), U3.6 (VDD)
!INT: JP3.6, U3.3 (!INT)
!RESET: D1.C, JP3.7
!RST_3V: D1.A, R2.2 (1), U3.2 (!RST)
!WAKE: D2.C, JP3.8, SJ2.1
!WAKE_3V: D2.A, R2.4 (1), U3.7 (!WAKE)
ADDR: R2.3 (1), SJ1.1, U3.1 (ADDR)
AUX: U3.8 (AUX)
GND: C4.2, C5.2, C6.2, CONN3.1 (GND), CONN3.MT1 (MT), CONN3.MT2 (MT), CONN4.1 (GND), CONN4.MT1 (MT), CONN4.MT2 (MT), D3.C, JP3.3, R2.6 (2), SJ2.2, U1.2 (GND), U3.THERMAL (GND)
unnamed: D3.A, R2.8 (2)
SCL: CONN3.4 (SCL), CONN4.4 (SCL), JP3.4, Q2.6 (D), R3.8 (2)
SCL_3V: Q2.1 (S), R3.7 (2), U3.10 (SCL)
SDA: CONN3.3 (SDA), CONN4.3 (SDA), JP3.5, Q2.3 (D), R3.6 (2)
SDA_3V: Q2.4 (S), R3.5 (2), U3.9 (SDA)
SENSE: U3.4 (PWM), U3.5 (SENSE)
VCC: C4.1, CONN3.2 (V+), CONN4.2 (V+), JP3.1, R3.1, R3.3 (1), U1.1 (IN), U1.3 (EN)

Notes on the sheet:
I2C Pullups & Shift
STEMMA/I2C Headers
ON LED
Power supply
Set default WAKE to LOW (woken up) Cut to use pin!

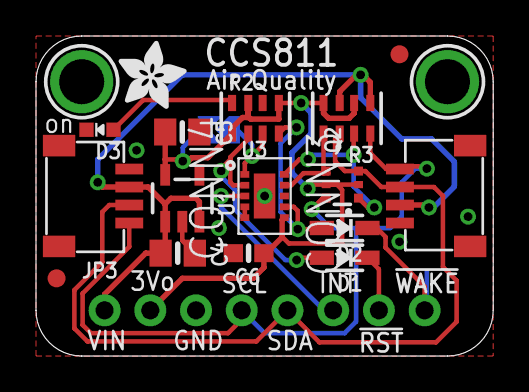
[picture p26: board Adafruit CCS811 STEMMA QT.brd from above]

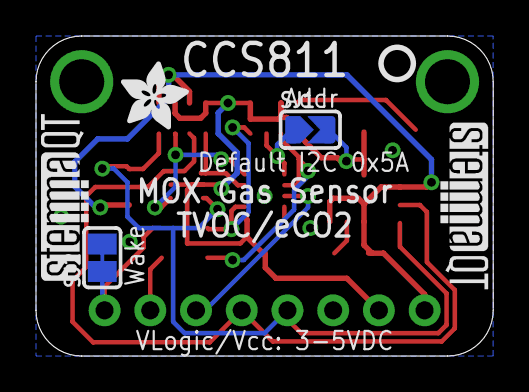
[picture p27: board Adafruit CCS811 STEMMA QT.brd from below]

Board: 2 copper layers, 25.4 x 17.8 mm, 25 parts (6 on the bottom side), 15 nets.

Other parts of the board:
U$1, U$45: ADAFRUIT_3.5MM
U$46: PCBFEAT-REV-040
U$47, U$48: STEMMAQT

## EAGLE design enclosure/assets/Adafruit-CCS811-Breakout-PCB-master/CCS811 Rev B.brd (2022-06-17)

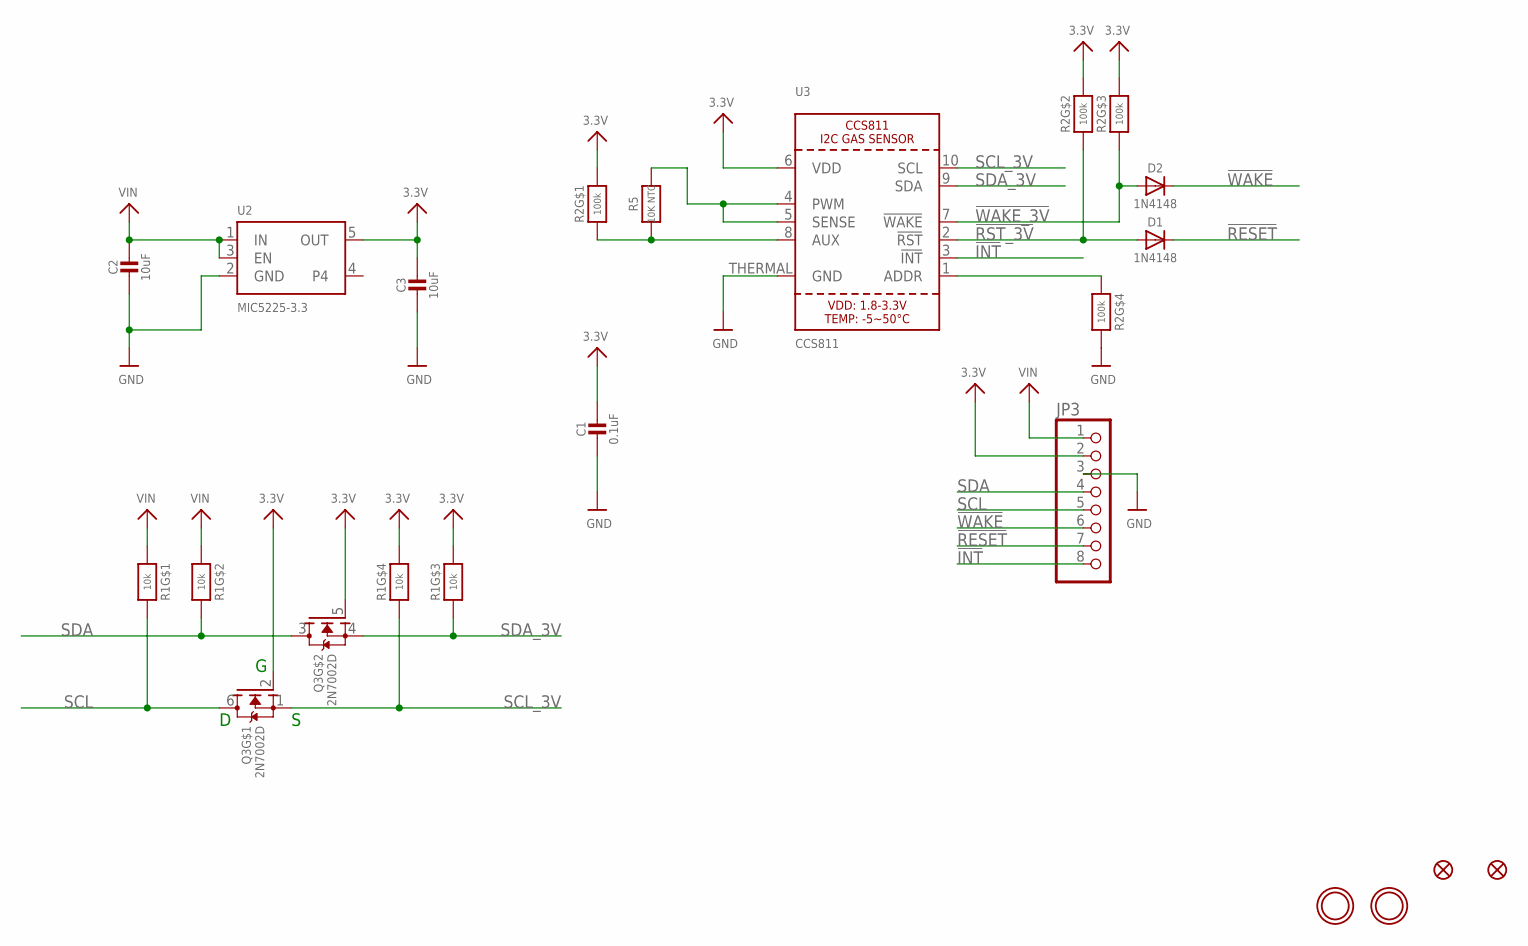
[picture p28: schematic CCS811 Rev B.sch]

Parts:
C1: 0.1uF; 0603-NO
C2, C3: 10uF; 0805-NO
D1, D2: 1N4148; SOD-323
FID1, FID2: FIDUCIAL_1MM
JP3: HEADER-1X870MIL; 1X08_ROUND_70
Q3: 2N7002D; SOT363
R1: 10k; RESPACK_4X0603
R2: 100k; RESPACK_4X0603
R5: 10K NTC; _0402
U2: MIC5225-3.3; SOT23-5
U3: CCS811
U$3, U$4: MOUNTINGHOLE2.5; MOUNTINGHOLE_2.5_PLATED

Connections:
3.3V: C1.1, C3.1, JP3.2, Q3.2 (G), Q3.5 (G), R1.3 (1), R1.4 (1), R2.6 (2), R2.7 (2), R2.8 (2), U2.5 (OUT), U3.6 (VDD)
!INT: JP3.8, U3.3 (!INT)
!RESET: D1.C, JP3.7
!RST_3V: D1.A, R2.2 (1), U3.2 (!RST)
!WAKE: D2.C, JP3.6
!WAKE_3V: D2.A, R2.3 (1), U3.7 (!WAKE)
GND: C1.2, C2.2, C3.2, JP3.3, R2.5 (2), U2.2 (GND), U3.THERMAL (GND)
unnamed: R5.2, U3.4 (PWM), U3.5 (SENSE)
unnamed: R2.1, R5.1, U3.8 (AUX)
unnamed: R2.4 (1), U3.1 (ADDR)
SCL: JP3.5, Q3.6 (D), R1.8 (2)
SCL_3V: Q3.1 (S), R1.5 (2), U3.10 (SCL)
SDA: JP3.4, Q3.3 (D), R1.7 (2)
SDA_3V: Q3.4 (S), R1.6 (2), U3.9 (SDA)
VIN: C2.1, JP3.1, R1.1, R1.2 (1), U2.1 (IN), U2.3 (EN)


Board: 2 copper layers, 20.3 x 17.8 mm, 18 parts (1 on the bottom side), 15 nets.

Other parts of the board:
U$1: ADAFRUIT_3.5MM
U$8: ADAFRUIT_2.5MM

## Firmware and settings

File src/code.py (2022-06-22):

import time
from adafruit_magtag.magtag import MagTag
from adafruit_magtag.graphics import Graphics
from adafruit_progressbar.progressbar import HorizontalProgressBar
from adafruit_display_shapes.line import Line
from adafruit_display_shapes.rect import Rect
import board
import alarm
import internet
import sensors




sensors.init_connected_sensors()

magtag = MagTag(rotation=0)

# magtag.peripherals.play_tone(440, 0.2)
# magtag.peripherals.play_tone(880, 0.2)
# time.sleep(0.2)
# magtag.peripherals.play_tone(440, 0.2) 


BIG_STYLE = dict(
            text_scale=1,
            text_font="fonts/FuturaBT-Heavy-48.bdf")

MEDIUM_STYLE = dict(
            text_scale=1,
            text_font="fonts/FuturaBT-Heavy-24.bdf")


SMALL_STYLE = dict(
            text_scale=1,
            text_font="fonts/FuturaBT-Medium-18.bdf")


W = magtag.graphics.display.width
MidW = W//2
H = magtag.graphics.display.height
M = 3 # Margin


SLEEP = True
TEMP_HUMIDITY_SINGLE_LINE = False

print(sensors.enabled_sensors)

def get_battery_progress():
    progress = 100*(magtag.peripherals.battery-3.6)/(4.1-3.6)
    if(progress > 100):
        progress = 100
    elif (progress < 0):
        progress = 0
    return progress


# # Create a new progress_bar object at (x, y)
progress_bar = HorizontalProgressBar(
    (W-30-M, H-10 - M),
    (30, 10),
    fill_color=0xFFFFFF,
    outline_color=0x000000,
    bar_color=0x777777,
)
magtag.graphics.splash.append(progress_bar)
progress_bar.progress = get_battery_progress()

texts = dict()
index = 0
current_position = 0
small_font_height = 17
medium_font_height = 25
big_font_height = 40


def set_text(name, text, auto_refresh=False):
    magtag.set_text(text, texts[name], auto_refresh)
    

def add_text(name, text_position, text_scale, text_font, text_anchor_point, initial_text = None):
    global index
    global texts
    texts[name] = index
    index+= 1
    magtag.add_text(
            text_position=text_position,
            text_scale=text_scale,
            text_font=text_font,
            text_anchor_point=text_anchor_point
    )
    if(initial_text is not None):
        set_text(name, initial_text, auto_refresh=False)


current_position = M

if(sensors.enabled_sensors['SCD41']):
    add_text( 
            "CO2_title",
            text_position=(M,current_position,),
            text_anchor_point=(0, 0),  # top left,
            initial_text="CO2",
            **SMALL_STYLE
    )

    add_text( 
            "ppm_title",
            text_position=(W - M, current_position,),
            text_anchor_point=(1, 0),  # top right,
            initial_text="ppm",
            **SMALL_STYLE
    )

    current_position += small_font_height

    add_text(
            "CO2_value",
            text_position=(W - M,current_position,),
            text_anchor_point=(1, 0),  # top right
            **BIG_STYLE
    )

    current_position += big_font_height

    if TEMP_HUMIDITY_SINGLE_LINE:
        magtag.graphics.splash.append(Line(MidW + M, current_position + M, MidW + M, current_position+small_font_height+medium_font_height - M , 0x000000))
        add_text( 
                "temp_title",
                text_position=(M,current_position,),
                text_anchor_point=(0, 0),  # top left,
                initial_text="Temp",
                **SMALL_STYLE
        )

        add_text( 
                "hum_title",
                text_position=(W - M, current_position,),
                text_anchor_point=(1, 0),  # top right,
                initial_text="Hum",
                **SMALL_STYLE
        )

        current_position += small_font_height

        add_text(
            "Temp_value",
                text_position=(M, current_position,),
                text_anchor_point=(0, 0),  # top left
                **MEDIUM_STYLE
        )

        add_text(
            "humidity_value",
                text_position=(W - M,current_position,),
                text_anchor_point=(1, 0),  # top right
                **MEDIUM_STYLE
        )
        current_position += medium_font_height
    else:
        add_text( 
                "temp_title",
                text_position=(M,current_position,),
                text_anchor_point=(0, 0),  # top left,
                initial_text="Temperature",
                **SMALL_STYLE
        )
        current_position += small_font_height

        add_text(
            "Temp_value",
                text_position=(W - M, current_position,),
                text_anchor_point=(1, 0),  # top right
                **BIG_STYLE
        )
        current_position += big_font_height

        add_text( 
                "hum_title",
                text_position=(M, current_position,),
                text_anchor_point=(0, 0),  # top right,
                initial_text = u"Rel.\xa0Humidity",
                **SMALL_STYLE
        )

        current_position += small_font_height

        add_text(
            "humidity_value",
                text_position=(W - M,current_position,),
                text_anchor_point=(1, 0),  # top right
                **BIG_STYLE
        )
        current_position += big_font_height



if(sensors.enabled_sensors['PM25']):
    magtag.graphics.splash.append(Line(MidW + M, current_position + M, MidW + M, current_position+small_font_height+medium_font_height - M , 0x000000))
    add_text( 
            "P3um_title",
            text_position=(M,current_position,),
            text_anchor_point=(0, 0),  # top left,
            initial_text="P>3um",
            **SMALL_STYLE
    )

    add_text( 
            "PM1.0_title",
            text_position=(W-M,current_position,),
            text_anchor_point=(1, 0),  # top left,
            initial_text="PM1.0",
            **SMALL_STYLE
    )

    current_position += small_font_height

    add_text(
        "P3um_Value",
            text_position=(M, current_position,),
            text_anchor_point=(0, 0),  # top left
            **MEDIUM_STYLE
    )

    add_text(
        "PM1.0_Value",
            text_position=(W-M, current_position,),
            text_anchor_point=(1, 0),  # top left
            **MEDIUM_STYLE
    )

    current_position += medium_font_height

    magtag.graphics.splash.append(Line(MidW + M, current_position + M, MidW + M, current_position+small_font_height+medium_font_height - M , 0x000000))


    add_text( 
            "P25_title",
            text_position=(M,current_position,),
            text_anchor_point=(0, 0),  # top left,
            initial_text="PM2.5",
            **SMALL_STYLE
    )

    add_text( 
            "PM10_title",
            text_position=(W-M,current_position,),
            text_anchor_point=(1, 0),  # top left,
            initial_text="PM10",
            **SMALL_STYLE
    )

    current_position += small_font_height

    add_text(
        "P2.5_Value",
            text_position=(M, current_position,),
            text_anchor_point=(0, 0),  # top left
            **MEDIUM_STYLE
    )

    add_text(
        "PM10_Value",
            text_position=(W-M, current_position,),
            text_anchor_point=(1, 0),  # top left
            **MEDIUM_STYLE
    )

    current_position += medium_font_height


if(sensors.enabled_sensors['CCS811']):
    add_text( 
            "VOC_title",
            text_position=(M,current_position,),
            text_anchor_point=(0, 0),  # top left,
            initial_text="TVOC\xa0ppb",
            **SMALL_STYLE
    )

    # add_text( 
    #         "ppb_title2",
    #         text_position=(W-M,current_position,),
    #         text_anchor_point=(1, 0),  # top left,
    #         initial_text="ppb",
    #         **SMALL_STYLE
    # )

    current_position += small_font_height

    add_text(
        "TVOC_Value",
            text_position=(W-M - 40, current_position,),
            text_anchor_point=(1, 0),  # top left
            **MEDIUM_STYLE
    )

    current_position += medium_font_height



# magtag.set_text("%d" % scd4x.CO2, 2, auto_refresh=False)
# magtag.set_text("%0.f°C" % scd4x.temperature, 3, auto_refresh=False)
# magtag.set_text("%0.f%%" % scd4x.relative_humidity, 4, auto_refresh=False)


# magtag.add_text(text_position=(225,10,),text_scale=2,) #  Battery

# magtag.refresh()
# while True:
#     pass

magtag.peripherals.neopixel_disable = True
magtag.peripherals.buttons[0].deinit()
a_alarm = alarm.pin.PinAlarm(pin=board.BUTTON_A, value=False, pull=True) #note pull

while True:
    if(magtag.peripherals.button_b_pressed):
        SLEEP = not SLEEP
    sensors.refresh_readings()
    if(sensors.enabled_sensors['SCD41']):
        set_text(name = "CO2_value", text= "%d" % sensors.readings['CO2'], auto_refresh=False)
        set_text(name = "Temp_value", text= "%0.f°C" % sensors.readings['temperature'], auto_refresh=False)
        set_text(name = "humidity_value", text= "%0.f%%" % sensors.readings['relative_humidity'], auto_refresh=False)
    if(sensors.enabled_sensors['CCS811']):
        set_text(name = "TVOC_Value", text= "%d" % sensors.readings['TVOC'], auto_refresh=False)
        # set_text(name = "eCO2_Value", text= "%d" % sensors.readings['eCO2'], auto_refresh=False)
    if(sensors.enabled_sensors['PM25']):
        set_text(name = "P3um_Value", text= "%d" % sensors.readings['particles 03um'], auto_refresh=False)
        set_text(name = "PM1.0_Value", text= "%d" % sensors.readings['pm10 standard'], auto_refresh=False)
        set_text(name = "P2.5_Value", text= "%d" % sensors.readings['pm25 standard'], auto_refresh=False)
        set_text(name = "PM10_Value", text= "%d" % sensors.readings['pm100 standard'], auto_refresh=False)
    progress_bar.progress = get_battery_progress()
    magtag.refresh()
    try:
        internet.connect_to_internet()
        internet.send_battery_level(magtag.peripherals.battery)
    except Exception:
        print('Could not send battery level')
    if(SLEEP):
        sensors.put_sensors_to_sleep()
        time_alarm = alarm.time.TimeAlarm(monotonic_time=time.monotonic() + 600) # 600 seconds = 5 minutes
        alarm.exit_and_deep_sleep_until_alarms(time_alarm, a_alarm)
    else:
        time.sleep(1)

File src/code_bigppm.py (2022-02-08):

# SPDX-FileCopyrightText: 2017 Scott Shawcroft, written for Adafruit Industries
#
# SPDX-License-Identifier: Unlicense
import time
from adafruit_magtag.magtag import MagTag
from adafruit_magtag.graphics import Graphics
import board
import alarm
# from adafruit_progressbar.progressbar import HorizontalProgressBar


import adafruit_scd4x
import adafruit_ccs811
# import adafruit_bme680
from adafruit_pm25.i2c import PM25_I2C
from mics6814 import MICS6814
# import busio

i2c = board.I2C()  # uses board.SCL and board.SDA
# i2c = busio.I2C(board.SCL, board.SDA)

magtag = MagTag()


SLEEP = True
use_ccs811 = False
use_pm25 = True
# use_bme688 = False
use_MICS6814 = False
use_SCD41 = True
BIG_PPM = True


if(use_ccs811):
    ccs811 = adafruit_ccs811.CCS811(i2c)
    # Wait for the sensor to be ready
    while not ccs811.data_ready:
        pass
    # magtag.set_text("CO2: {} PPM\n TVOC: {} PPB".format(ccs811.eco2, ccs811.tvoc))

if(use_pm25):
    pm25_reset_pin = None
    pm25 = PM25_I2C(i2c, pm25_reset_pin)
    aqdata = None
    while aqdata is None:
        try:
            aqdata = pm25.read()
            # print(aqdata)
        except RuntimeError:
            print("Unable to read from sensor, retrying...")
            time.sleep(1)
    # magtag.set_text(
    #     "PM 1.0: %d\tPM2.5: %d\tPM10: %d"
    #     % (aqdata["pm10 standard"], aqdata["pm25 standard"], aqdata["pm100 standard"])
    # )

if(use_SCD41):
    scd4x = adafruit_scd4x.SCD4X(i2c)
    scd4x.start_periodic_measurement()
    while scd4x.CO2 is None :
        time.sleep(0.1)
    # magtag.set_text("CO2: %d ppm" % scd4x.CO2)
    # magtag.set_text("Temperature: %0.1f *C" % scd4x.temperature)
    # magtag.set_text("Humidity: %0.1f %%" % scd4x.relative_humidity)

# if(use_bme688):
#     bme680 = adafruit_bme680.Adafruit_BME680_I2C(i2c, debug=False, address=0x76)
#     # change this to match the location's pressure (hPa) at sea level
#     bme680.sea_level_pressure = 1013.25
#     # You will usually have to add an offset to account for the temperature of
#     # the sensor. This is usually around 5 degrees but varies by use. Use a
#     # separate temperature sensor to calibrate this one.
#     temperature_offset = -5
#     # print("\nTemperature: %0.1f C" % (bme680.temperature + temperature_offset))
#     # print("Gas: %d ohm" % bme680.gas)
#     # print("Humidity: %0.1f %%" % bme680.relative_humidity)
#     # print("Pressure: %0.3f hPa" % bme680.pressure)
#     # print("Altitude = %0.2f meters" % bme680.altitude)

if use_MICS6814:
    mics6814 = MICS6814(i2c)
    mics6814.set_led(20,0,0)
    mics6814.set_brightness(0.1)
    print(mics6814.read_all())

if(BIG_PPM):
    magtag.add_text(text_position=(3,90,),text_scale=3,
    text_font="fonts/Arial-Bold-12.pcf",
    ) #Temp
    magtag.add_text(text_position=(190,90,),text_scale=3,
    text_font="fonts/Arial-Bold-12.pcf",
    ) #Hum
    magtag.add_text(text_position=(3,30,),text_scale=4,
    text_font="fonts/Arial-Bold-12.pcf",
    ) # CO2
else:
    magtag.add_text(text_position=(3,5,),text_scale=2,) #Temp
    magtag.add_text(text_position=(3,25,),text_scale=2,) #Hum
    magtag.add_text(text_position=(3,45,),text_scale=2,) # CO2
magtag.add_text(text_position=(3,65,),text_scale=2,) #  bme688 GAS 
magtag.add_text(text_position=(3,85,),text_scale=2,) #  bme688 GAS
magtag.add_text(text_position=(3,105,),text_scale=2,) #  bme688 GAS

magtag.add_text(text_position=(225,10,),text_scale=2,) #  Battery



# # Create a new progress_bar object at (x, y)
# progress_bar = HorizontalProgressBar(
#     (200, 20),
#     (30, 10),
#     bar_color=0xFFFFFF,
#     outline_color=0xAAAAAA,
#     fill_color=0x777777,
# )



# set up pin alarms
# pin_alarms = [alarm.pin.PinAlarm(pin=board.BUTTON_, value=False, pull=True)]

magtag.peripherals.neopixel_disable = True
magtag.peripherals.buttons[0].deinit()
a_alarm = alarm.pin.PinAlarm(pin=board.BUTTON_A, value=False, pull=True) #note pull

while True:
    if(magtag.peripherals.button_b_pressed):
        SLEEP = not SLEEP
    # for i, b in enumerate(magtag.peripherals.buttons):
    #     if not b.value:
    #         print("Button %c pressed" % chr((ord("A") + i)))
    #         magtag.peripherals.neopixel_disable = False
    #         magtag.peripherals.neopixels.fill(button_colors[i])
    #         magtag.peripherals.play_tone(button_tones[i], 0.25)
    #         break
    # else:
    #   magtag.peripherals.neopixel_disable = True
    if(use_SCD41):
        if(BIG_PPM):
            magtag.set_text("%0.f°C" % scd4x.temperature, 0, auto_refresh=False)
            magtag.set_text("%0.f%%" % scd4x.relative_humidity, 1, auto_refresh=False)
            magtag.set_text("%dppm" % scd4x.CO2, 2, auto_refresh=False)
        else:
            magtag.set_text("T %0.1f*C" % scd4x.temperature, 0, auto_refresh=False)
            magtag.set_text("H %0.1f%%" % scd4x.relative_humidity, 1, auto_refresh=False)
            magtag.set_text("CO2 %dppm" % scd4x.CO2, 2, auto_refresh=False)
    # if(use_bme688):
    #     # magtag.set_text("T %0.1f*C" % float(bme680.temperature) + temperature_offset, 0, auto_refresh=False)
    #     magtag.set_text("GAS %dohm" % bme680.gas, 2, auto_refresh=False)
    #     # print("\nTemperature: %0.1f C" % ())
    if(use_pm25):
        try:
            aqdata = pm25.read()
            magtag.set_text(
                "PM1.0 %d" % (aqdata["pm10 standard"]),
                 2, auto_refresh=False)
            magtag.set_text(
                "PM2.5 %d" % (aqdata["pm25 standard"]),
                 3, auto_refresh=False)
            magtag.set_text(
                "PM10 %d" % (aqdata["pm100 standard"]),
                 4, auto_refresh=False)
        except RuntimeError:
            print("Unable to read from sensor, retrying...")

    voltage = magtag.peripherals.battery
    if(SLEEP):
        magtag.set_text("S %f" % voltage, 6, auto_refresh=False)
    else:
        magtag.set_text("W %f" % voltage, 6, auto_refresh=False)
    magtag.refresh()
    if(SLEEP):
        if(use_SCD41):
            scd4x.stop_periodic_measurement()
        # alarm.exit_and_deep_sleep_until_alarms(*pin_alarms)
        time_alarm = alarm.time.TimeAlarm(monotonic_time=time.monotonic() + 600) # 600 seconds = 5 minutes
        alarm.exit_and_deep_sleep_until_alarms(time_alarm, a_alarm)
        # magtag.exit_and_deep_sleep(10*60)  # 5 minutes
    else:
        time.sleep(1)

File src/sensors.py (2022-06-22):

import board
import alarm
import time

import busio

i2c = busio.I2C(board.SCL, board.SDA)

import PCA9536

i2cSwitch = PCA9536.PCA9536(i2c)

pm25 = None
scd4x = None
mics6814 = None
ccs811 = None

CCS811_LOW_POWER_MODE = None

enabled_sensors = dict(
		PM25 = False,
		SCD41 = False,
		MICS6814 = False,
		CCS811 = False,
	)
# print(i2cSwitch.read(0))

def init_sensor(sensor):
	global pm25
	global scd4x
	global mics6814
	global ccs811
	global CCS811_LOW_POWER_MODE
	if(sensor == 'PM25'):
		from adafruit_pm25.i2c import PM25_I2C
		pm25_reset_pin = None
		pm25 = PM25_I2C(i2c, pm25_reset_pin)
		aqdata = pm25.read()
		while aqdata is None:
			try:
				aqdata = pm25.read()
			except RuntimeError:
				print('loading')
				time.sleep(0.1)
		# print('aqdata', aqdata)
	elif(sensor == 'SCD41'):
		import adafruit_scd4x
		scd4x = adafruit_scd4x.SCD4X(i2c)
		scd4x.start_periodic_measurement()
		while scd4x.CO2 is None :
			time.sleep(0.1)
	elif(sensor == 'MICS6814'):
		from mics6814 import MICS6814 
		mics6814 = MICS6814(i2c)
		# mics6814.set_led(0,0,0)
		# mics6814.set_brightness(0)
	elif(sensor == 'CCS811'):
		import adafruit_ccs811
		ccs811 = adafruit_ccs811.CCS811(i2c)
		CCS811_LOW_POWER_MODE = adafruit_ccs811.DRIVE_MODE_60SEC
		# Wait for the sensor to be ready
		while not ccs811.data_ready:
			time.sleep(0.1)

readings = dict()

def refresh_readings():
	global pm25
	global scd4x
	global mics6814
	global ccs811
	#i2cSwitch.powerOn()
	# if(enabled_sensors['PM25']):
		# init_sensor('PM25')
	if(enabled_sensors['SCD41']):
		readings['CO2'] = scd4x.CO2
		readings['temperature'] = scd4x.temperature
		readings['relative_humidity'] = scd4x.relative_humidity
	# if enabled_sensors['MICS6814']:
	if enabled_sensors['CCS811']:
		readings['TVOC'] = ccs811.tvoc
		readings['eCO2'] = ccs811.eco2
	if enabled_sensors['PM25']:
		try:
			aqdata = pm25.read()
			readings['pm10 env'] = aqdata['pm10 env']
			readings['pm25 env'] = aqdata['pm25 env']
			readings['pm100 env'] = aqdata['pm100 env']
			readings['pm10 standard'] = aqdata['pm10 standard']
			readings['pm25 standard'] = aqdata['pm25 standard']
			readings['pm100 standard'] = aqdata['pm100 standard']
			readings['particles 03um'] = aqdata['particles 03um']
			readings['particles 05um'] = aqdata['particles 05um']
			readings['particles 10um'] = aqdata['particles 10um']
			readings['particles 25um'] = aqdata['particles 25um']
			readings['particles 50um'] = aqdata['particles 50um']
			readings['particles 100um'] = aqdata['particles 100um']
		except RuntimeError:
			readings['pm10 env'] = -1
			readings['pm25 env'] = -1
			readings['pm100 env'] = -1
			readings['pm10 standard'] = -1
			readings['pm25 standard'] = -1
			readings['pm100 standard'] = -1
			readings['particles 03um'] = -1
			readings['particles 05um'] = -1
			readings['particles 10um'] = -1
			readings['particles 25um'] = -1
			readings['particles 50um'] = -1
			readings['particles 100um'] = -1

	return readings



def put_sensors_to_sleep():
	global pm25
	global scd4x
	global mics6814
	global ccs811
	if(enabled_sensors['SCD41']):
		scd4x.stop_periodic_measurement()
	if(enabled_sensors['CCS811']):
		ccs811.drive_mode = CCS811_LOW_POWER_MODE
	i2cSwitch.powerOff()


def get_connected_sensors():
	global enabled_sensors
	while not i2c.try_lock():
		time.sleep(0.1)

	addresses = i2c.scan()
	i2c.unlock()

	print("Detected i2C addresses", [hex(a) for a in addresses])

	print('''

	# 	PM25 = 0x12 = 18
	# 	SCD41 = 0x62 = 98
	# 	MICS6814 = 0x19 = 25
	# 	CCS811 = 0x5a = 90
	#  	Switch = 0x41 = 65
	#	Accelero = 0x19 = 25
		''')

	# enabled_sensors = dict(
	# 	PM25 = False,
	# 	SCD41 = True,
	# 	MICS6814 = False,
	# 	CCS811 = False,
	# )
	enabled_sensors = dict(
		PM25 = 0x12 in addresses,
		SCD41 = 0x62 in addresses,
		MICS6814 = False,#0x19 in addresses and 0x12 in addresses,
		CCS811 = 0x5a in addresses,
	)
	print(enabled_sensors)


def init_connected_sensors():
	i2cSwitch.powerOff()
	time.sleep(0.1)
	i2cSwitch.powerOn()
	time.sleep(3)
	get_connected_sensors()


	if(enabled_sensors['PM25']):
		init_sensor('PM25')
	if(enabled_sensors['SCD41']):
		init_sensor('SCD41')
	if enabled_sensors['MICS6814']:
		init_sensor('MICS6814')
	if enabled_sensors['CCS811']:
		init_sensor('CCS811')

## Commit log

2021-12-12 Add voltage indicator
2022-02-03 Add support for wake on button
2022-03-02 Update to auto detect sensors on start
2022-06-17 Add enclosure V1
    [4632 PMSA003I.f3d, 5Pin.step, 5x_Male_Pin_2.54_mm.STEP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]
2022-06-24 Add MICS6814 Qwiic board
    [mics6814_qwiic.kicad_pcb, mics6814_qwiic.kicad_sch]
2022-06-24 Board update
    [mics6814_qwiic.kicad_pcb]
2022-06-24 Rounded corners
    [mics6814_qwiic.kicad_pcb]
2022-06-24 Fix minor issues and MSSOP
    [mics6814_qwiic.csv, mics6814_qwiic.kicad_sch]
2022-06-24 Add index to MICS6814
    [mics6814_qwiic.kicad_pcb]
2022-06-24 Flex !
    [mics6814_qwiic.kicad_pcb]

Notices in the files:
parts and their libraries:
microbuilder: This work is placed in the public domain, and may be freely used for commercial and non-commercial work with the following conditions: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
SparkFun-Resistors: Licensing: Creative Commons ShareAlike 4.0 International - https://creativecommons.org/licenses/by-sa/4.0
